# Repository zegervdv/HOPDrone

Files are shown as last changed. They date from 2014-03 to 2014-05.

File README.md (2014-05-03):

HOPDrone
========

Indoor localization for drones

## Code

For Least Mean Square implementation: checkout `code-lms`.

For Kalman implementation: checkout `code-kalman`.

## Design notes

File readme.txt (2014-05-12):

-- besluit !!
-- design vereisten
-- accelerometer => niet enkel handig voor kalman maar ook voor energiebesparing
	voelt de accelerometer een versnelling dan kan de filter worden aangezet (dynamic power management)
-- nlos => lange rise time(zorg voor redundantie en smijt nlos metingen eruit of sla een stap over na het opmerken van nLos en pas dead reckoning toe) 
   ook saturatie resultaten mag je niet zomaar gebruiken
-- kalman filter bank => meerdere parallelle filters ( 1 voor bv stilstaan, 1 voor snel voortbewegen, ...)
		--> residu: vergelijk de te verwachten waarde met wat je uitkomt, is dit sterk verschillend dan geef je aan die parallelle filter een laag gewicht

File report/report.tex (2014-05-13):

\documentclass[a4paper]{article}        % Standaard een kolom layout
\usepackage[english]{babel}             % Stel woordafbrekingen en referentienamen in
\usepackage{graphicx}                   % Afbeeldingen weergeven
\usepackage{float}                      % Figuren op plaats waar ze gedefinieerd staan: [H]
\usepackage{lmodern}                     % Lettertype instellen op Helvetica
\usepackage[T1]{fontenc}
\usepackage[hidelinks]{hyperref}        % Referenties aanklikbaar in PDF, geen kaders rond weergeven
\usepackage{siunitx}                    % SI unit symbolen
\usepackage{amsmath}                    % Matrices en vergelijkingen
\usepackage{subcaption}                 % Subfiguren
\usepackage[parfill]{parskip}			% Niet inspringen aan begin alinea
\usepackage{epstopdf}

% \title{Hardware Design Project\\ Designing a drone positioning sensor}
% \author{Laurens Bogaert\\Thomas Deckmyn\\Zeger Van de Vannet}
% \date{\today}

\begin{document}

\include{titel}
% Inhoudstafel
\newpage
  \tableofcontents
\newpage

\section{Introduction}

The goal for this project is to make it possible to accurately localize drones indoors. This is a necessity when we, for example, want the drone to fly autonomously. GPS can be used outdoors but even then GPS is not ideal because of its limited accuracy (approximately $\SI{3}{\meter}$ in the azimuth plane and even worse in terms of determining the height of the drone). \\\\
To perform the indoor localization we will use a custom setup comprising of the TIME DOMAIN\texttrademark PulsOn 410 UWB module\footnote{\url{http://www.timedomain.com/p400.php}}, that relies on pulses, which have an UWB spectrum, to obtain distance measurements between two modules. Several of these P410 (or RCM) modules are placed at known locations in the room and act as anchors to determine the current location of the drone based on triangulation.

 In this project we will develop a custom UWB antenna that will be mounted on the drone and will be streamlined in order to reduce possible drag. Also, an extra circuit board will be designed to connect a microcontroller to one of the RCM P410 modules in order to process the measurements and determine the position. These modules can be used both for ranging measurements, as well as for wireless communication. The module with the microcontroller is attached to the drone and several other RCM modules are placed in the room or building to serve as anchor points. The microcontroller will perform all calculations needed to determine its position based on different localization algorithms. An additional RCM is connected to a computer which acts as a central control unit and also allows to visualize the position of the drone in a GUI in real time. 

\section{Antenna Design}
	
	 The P410 modules are already equipped with a TIME DOMAIN\texttrademark Broadspec UWB Antenna, a dipole that is omnidirectional in the azimuth plane. We will use the specifications of this antenna as design parameters for our own UWB antenna. The critical design parameters are listed below. 

	\begin{itemize}
		\item Radiate in the $\SI{3.1}{\giga\hertz}$ - $\SI{5.3}{\giga\hertz}$ band
		\item Nominal gain $\approx \SI{3}{\decibel}$
		\item Linear phase characteristic
		\item Efficiency $\approx$ 90\%	

	\end{itemize}

	In an indoor environment reflective surfaces are omnipresent, e.g. walls, metal cabinets etc. Hence multipath can be a severe problem if not taken into account. The ranging done by the RCM modules is performed by measuring the round trip time of a pulse travelling to an anchor point (with a well known location) and back. When multipath occurs the module mounted on the drone will receive multiple signals from an anchor point, i.e. reflected and direct waves. The reflected waves will have an added time delay because of which the module will not be able to obtain the correct distance. 
	The P410 modules used for this project already account for multipath, thus it will be no issue for the development of the indoor localization system.  

	\subsection{Antenna Topology and Design}
	\label{subsec:ant_design}

	At first we experiment with a few conventional UWB topologies like a bow tie and a barbell shape (see Figure \ref{fig:topologies}). After optimisation and simulation in ADS, we conclude that the simulated S-parameters and gain are not compliant with the design parameters above. Obtaining a linear phase characteristic with these topologies proves to be very hard as well.  

		\begin{figure}[H]
		\begin{subfigure}{0.5\textwidth}
			\centering
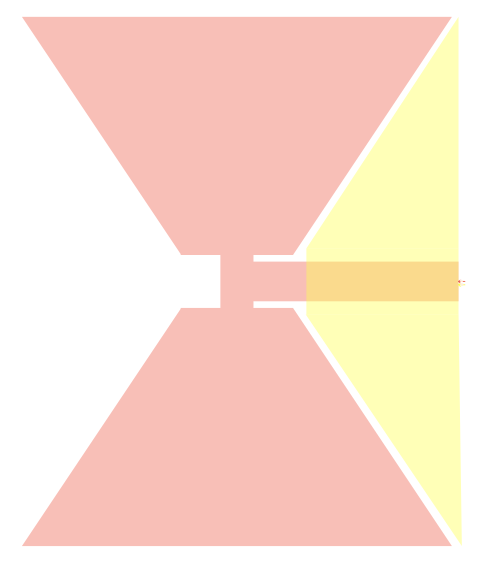
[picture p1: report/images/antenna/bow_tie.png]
			
			\caption{Bow Tie Topology}
		\end{subfigure}
		\begin{subfigure}{0.5\textwidth}
			\centering
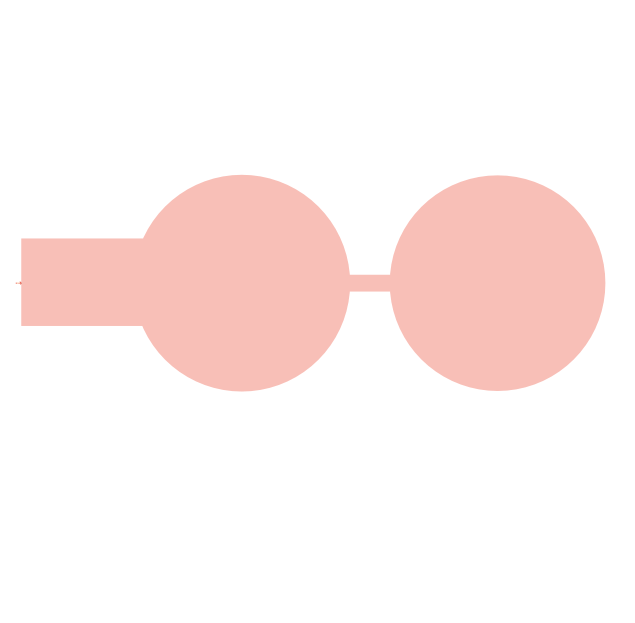
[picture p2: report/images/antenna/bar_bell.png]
			
			\caption{Barbell Topology}
		\end{subfigure}
		\caption{UWB Antenna Topologies}
		\label{fig:topologies}
		\end{figure} 

	The substrate material that is being used to design the antenna is \textit{Black Foam} with a low relative permittivity $\epsilon_r = 1.495$. Hence we encounter a practical problem with respect to the dimension of the antenna, i.e. if the antenna needs to be constructed with this substrate, its dimension will be too large to mount on the drone. Thus for the remaining part of the design process we opt for an \textit{Aromated Polyurethane} substrate with a higher $\epsilon_r = 2.55$, which allows us to work with smaller dimensions while radiating in the same frequency band. 

	After experimenting with the aforementioned exotic topologies, we redo the design starting from a rectangular microstrip patch antenna. The length of the patch determines the resonance frequency of the device, while the width has an influence on the radiated power. A wider patch means less resonance resistance, hence more bandwidth and a higher efficiency. 
	We want the resonance frequency of the patch to be in the predefined frequency band $\SI{3.1}{\giga\hertz}$ - $\SI{5.3}{\giga\hertz}$ and thus choose $f_0 = \SI{4.2}{\giga\hertz}$. Using Equation \eqref{eq:width_patch} we calculate the desired width of the patch.
	\begin{equation} 
	L = \frac{c}{2 f_r \sqrt{\epsilon_r}}
	\label{eq:width_patch}
	\end{equation}

  The bandwidth of the antenna needs to be very wide, thus, as explained above, we would be tempted to increase the width of the patch to obtain a larger bandwidth. Again, we are limited by the dimensions of the drone, because it needs to be fitted onto it and we do not want the antenna to interfere too much with the aerodynamics. To increase the bandwidth we apply another technique, i.e. adding stairs to the rectangular patch and optimizing their dimensions to obtain the desired bandwidth. Also, we introduce a partial ground plane (since UWB and a infinite ground plane do not coexist). We optimize the dimensions of the ground plane, to realize an approximately flat $S_{11}$ and a linear phase characteristic in the wanted frequency band. The final antenna lay-out is shown in Figure \ref{fig:patch_stairs} and the optimized dimensions are given in \autoref{tab:dimensions}.

	\begin{figure}[H]
	\centering
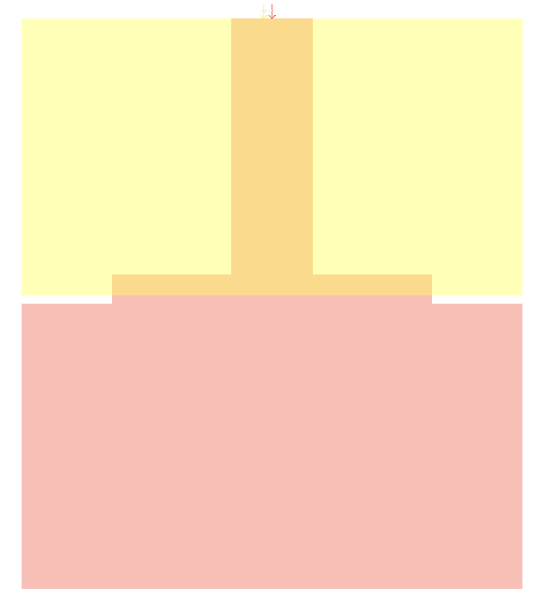
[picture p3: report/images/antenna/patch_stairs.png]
		
		\caption{Rectangular patch antenna with added stairs and partial ground plane}
		\label{fig:patch_stairs}
	\end{figure}

	\begin{table}[H]
	\centering
	\begin{tabular}{|c|c|}
		\hline
		\multicolumn{2}{|c|}{\textbf{Antenna}} \\ \hline
		L & $\SI{20.5}{\milli\meter}$ \\ \hline
		W & $\SI{36}{\milli\meter}$ \\ \hline
		$W_{stair}$ & $\SI{8.6}{\milli\meter}$ \\ \hline
		$H_{stair}$ & $\SI{2.1}{\milli\meter}$ \\ \hline
		\multicolumn{2}{|c|}{\textbf{Ground Plane}} \\ \hline
		L & $\SI{19.2}{\milli\meter}$ \\ \hline
		W & $\SI{36}{\milli\meter}$ \\ \hline 
	\end{tabular}
	\caption{Optimized dimensions for antenna and partial ground plane}
	\label{tab:dimensions}
	\end{table}

	\begin{figure}[H]
	\centering
	\begin{subfigure}[b]{0.52\textwidth}
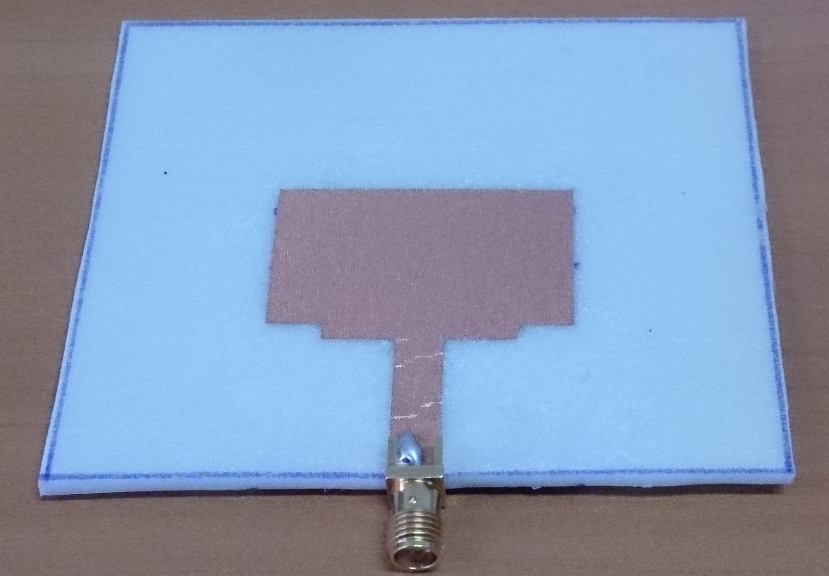
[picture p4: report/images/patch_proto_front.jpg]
                
                \caption{Front side prototype antenna}
                \label{fig:front_prototype}
        \end{subfigure}%
  ~      
        \begin{subfigure}[b]{0.5\textwidth}
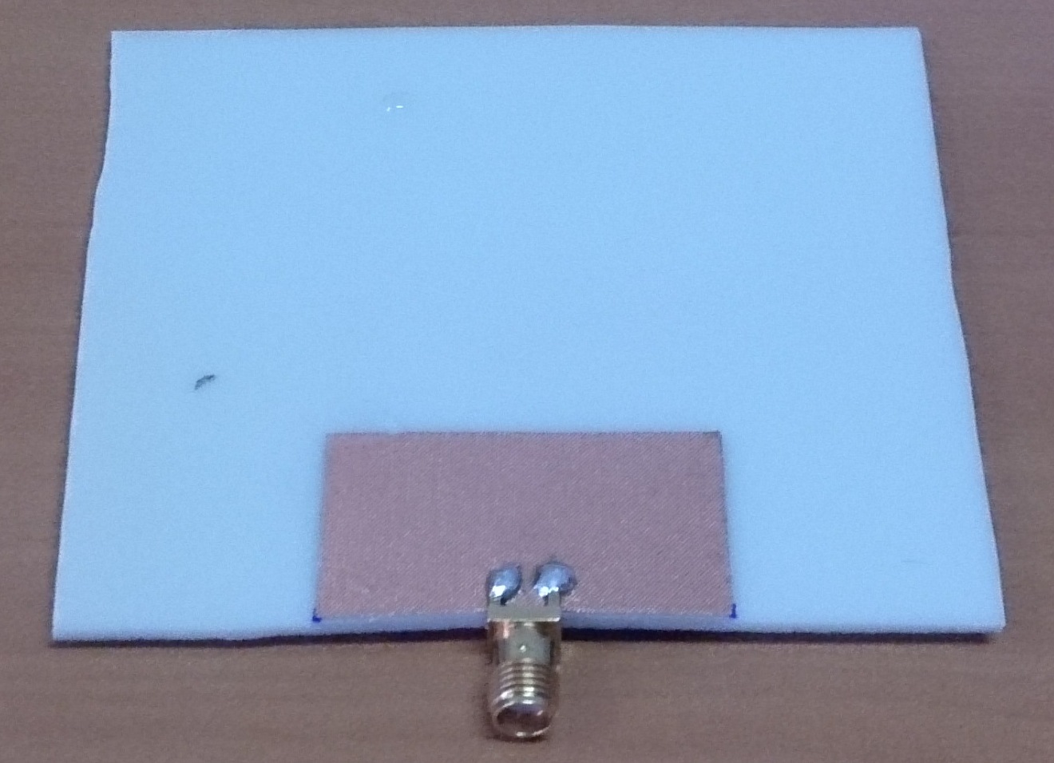
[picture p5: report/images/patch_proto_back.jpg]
                
                \caption{Back side prototype antenna}
                \label{fig:back_prototype}
        \end{subfigure}
	\end{figure}

	\subsection{Simulation}
		While designing the antenna, simulations in ADS Momentum\footnote{http://www.home.agilent.com/en/pc-1297113/advanced-design-system-ads} are used to confirm that the antenna's characteristics are as desired. In this section we will discuss the simulation results of the final design, as explained in the previous \autoref{subsec:ant_design}. 

		\begin{figure}[H]
		\begin{subfigure}{0.5\textwidth}
		\centering
			
			\caption{Simulated $S_{11}$}
		\end{subfigure}%
    ~
		\begin{subfigure}{0.5\textwidth}
		\centering
			
			\caption{Simulated phase response}
		\end{subfigure}
		\caption{Simulated characteristics for designed UWB antenna}
		\label{fig:S11_phase_design}
		\end{figure}

		\autoref{fig:S11_phase_design} shows that the $S_{11}$-parameter is below $\SI{-10}{\decibel}$, and relatively flat, in the desired frequency band. The phase characteristic proves to be approximately linear as well, which is in line with the design parameters. The gain is ca. $\SI{3}{\decibel}$ and the antenna efficiency is according to the simulation between 50\% and 96\%, with the latter occurring in the lower half of the frequency band. 
		Figure \ref{fig:ant_radpat_sim} shows the simulated radiation pattern of the designed UWB antenna.

		\begin{figure}[H]
		\centering
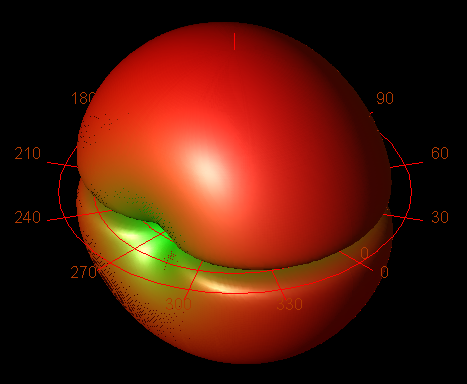
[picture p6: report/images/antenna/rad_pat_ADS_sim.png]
			
			\caption{Simulated radiation pattern at $\SI{4.5}{\giga\hertz}$}
			\label{fig:ant_radpat_sim}
		\end{figure}

	\subsection{Measurements}
		After the positive simulation results, we continue with the construction of the designed antenna. Due to a small misalignment between partial ground plane and antenna we need to construct a second version of the UWB antenna to obtain optimal results. Between these two versions, some minor adjustments are made to the design to further improve flatness of the $S_{11}$ and linearity of the phase, and to make it more robust to small alignment errors. The measured reflection coefficients of the two versions of the antenna are compared to the reference antenna and to the respective simulation in \autoref{fig:antenna_comp}. The initial measurements of the S-parameters of both versions suffered from noise due to common-mode current, which was solved by addition of a ferrite clamp.

		\begin{figure}[H]
			\centering
			
			\caption{Version 1 and 2 of constructed antenna compared to simulation and reference}
			\label{fig:antenna_comp}
		\end{figure}

		As seen in \autoref{fig:antenna_comp}, the first version of the antenna doesn't meet the pre-imposed design criteria, i.e.\ the $S_{11}$ is not less than $\SI{-10}{\decibel}$ over the entire frequency range of $\SI{3.1}{\giga\hertz}$ - $\SI{5.3}{\giga\hertz}$.
		The $S_{11}$ characteristic is improved by the better alignment in version 2 and the minor adjustments to the design.
		If we compare the measured $S_{11}$ to the simulation in Figure \ref{fig:S11_phase_design} we notice that the measured $S_{11}$ is below $\SI{-10}{\decibel}$ in the exact same frequency band that was predicted by the simulation. The main difference is the flatness of the characteristic and the resonance peak at approximately $\SI{5.2}{\giga\hertz}$. These deviations can be attributed to the manual fabrication of the antenna, the dimensions are not perfectly equal to the design and some slight misalignment is inevitable, or the fact that ADS Momentum assumes an infinite substrate to perform its simulations.\\\\

		\begin{figure}[H]
		\begin{subfigure}{0.5\textwidth}
			
			\caption{$\SI{3.1}{\giga\hertz}$}
		\end{subfigure}
		\begin{subfigure}{0.5\textwidth}
			
			\caption{$\SI{3.7}{\giga\hertz}$}
		\end{subfigure}
		\begin{subfigure}{0.5\textwidth}
			
			\caption{$\SI{4.8}{\giga\hertz}$}
		\end{subfigure}
		\begin{subfigure}{0.5\textwidth}
			
			\caption{$\SI{5}{\giga\hertz}$}
		\end{subfigure}
		\begin{subfigure}{\textwidth}
		\centering
			
			\caption{$\SI{5.3}{\giga\hertz}$}
		\end{subfigure}
		\caption{Radiation pattern in azimuth plane at different frequencies}
		\label{fig:ant_radpat}
		\end{figure}

		The radiation pattern in the azimuth plane of the designed UWB antenna at different frequencies is shown in Figure \ref{fig:ant_radpat}. We can state that the designed antenna is approximately omnidirectional in the azimuth plane up to $\SI{5}{\giga\hertz}$, which corresponds to the Broadspec UWB antenna used as a reference. It can also be seen that the radiation pattern starts to deviate from omnidirectional at $\SI{5}{\giga\hertz}$. Due to the resonance peak seen in Figure \ref{fig:antenna_comp} at approximately $\SI{5.2}{\giga\hertz}$ the antenna has a gain at $\SI{5.3}{\giga\hertz}$ that is larger than the pre-imposed $\SI{3}{\decibel}$. The transmit power of the RCM modules in standard mode can be adjusted within $[\SI{-31.6}{\decibel}m , \SI{-12.46}{\decibel}m]$ if needed, to comply with FCC regulations.\\\\
		
		\begin{figure}[H]
			\begin{subfigure}{0.5\textwidth}
			\centering
				
				\caption{$\SI{3.4}{\giga\hertz}$}
			\end{subfigure}
			\begin{subfigure}{0.5\textwidth}
			\centering
				
				\caption{$\SI{4.5}{\giga\hertz}$}
			\end{subfigure}
			\begin{subfigure}{\textwidth}
			\centering
				
				\caption{$\SI{5}{\giga\hertz}$}
			\end{subfigure}
		\caption{Cross section of radiation pattern in elevation plane}
		\label{fig:ant_radpat_elev}
		\end{figure}
			Figure \ref{fig:ant_radpat_elev} shows a cross section of the radiation pattern in the elevation plane at different frequencies. There is a zero in the radiation pattern for $\theta=0$ and $\theta=\pi$. The antenna will be mounted on the drone "upside down", i.e. $\theta$ = 0 will be oriented along the negative z-axis. As the drone will only pass directly over an anchor in very rare cases, the zero at $\theta=0$ will not cause problems for the localization system. Figure \ref{fig:mount_antenna} shows how the antenna will be mounted on the drone, thus the zero at $\theta=\pi$ is even beneficial as it minimizes the chance of interference and EMC problems inside the circuit of the drone. 

		\begin{figure}[H]
			\centering
			
			\caption{Mounting antenna on bottom of drone}
			\label{fig:mount_antenna}
		\end{figure}

\section{Location Algorithm}
	A first algorithm that can be used to determine the position of the drone is the \textit{Least Mean Square} algorithm. We will elaborate on this first and then compare the performance to the Unscented Kalman Filter, which will be used in the final system. 

	\subsection{Least Mean Square}
	\label{subsec:LMS}

		The LMS algorithm uses the distances between the drone and a number of well-known anchor points to determine the position. The UWB antenna mounted on the drone broadcasts a very short pulse to the anchors, which will return the same pulse when it is received. The board on the drone measures the time between sending the pulse and receiving the response. As the propagation speed in air of the pulse and the time it takes to process it at the anchors are known, the distance to the anchor points can be determined as follows:

		\begin{equation}
		\centering
			t_{roundtrip} = 2t_{propagation} + t_{process}
		\end{equation} 

		Because the time to process the pulse at the anchor is known, we are able to calculate the time it takes to bridge the distance from the drone to the anchor point or vice versa. With $c$ the speed of light ($\SI{3e8}{\meter\per\second}$) this results in an expression for the distance to anchor point $i$:

		\begin{equation}
		\centering
			d_i = c*t_{propagation}
		\end{equation}

		With $\vec{\textbf{x}}$ denoting the position vector $\begin{bmatrix} x & y & z \end{bmatrix}$ of the drone and $\vec{\textbf{x}_i}$ the position vector $\begin{bmatrix} x_i & y_i & z_i \end{bmatrix}$ of the $i^{th}$ anchor point, this distance can also be expressed as follows:

		\begin{align*}
		\centering
			d_i^2 &= (\vec{\textbf{x}} - \vec{\textbf{x}_i})(\vec{\textbf{x}} - \vec{\textbf{x}_i})^T \\
			&= x^2 - 2x_ix + x_i^2 + y^2 - 2y_iy + y_i^2 + z^2 - 2z_iz + z_i^2
		\end{align*}

		This equation is not linear in x, y and z and therefore it is hard to extract the position vector. With $d_N$ the distance to the $N^{th}$ anchor, the equation can be linearised as follows:

		\begin{align*}
		\centering
			d_i^2 - d_N^2 &= x^2 - 2x_ix + x_i^2 + y^2 - 2y_iy + y_i^2 + z^2 - 2z_iz + z_i^2 - d_N^2 \\
				&= 2x(x_N - x_i) + 2y(y_N - y_i) + 2z(z_N- z_i)+ (x_i^2 - x_N^2) + (y_i^2 - y_N^2)  + (z_i^2 - z_N^2) 
		\end{align*}

		This yields a matrix representation of the form $\textbf{A}\vec{\textbf{x}} = \textbf{B}$ which can be solved for the position vector $\vec{\textbf{x}}$.

	% subsection LMS (end)
	\subsection{Kalman Filtering}
	The second algorithm that is implemented is the Kalman Filter. This algorithm makes use of ``sensor'' fusion which in principle means that we try to combine data from several sensors to track the drone more accurately.
	Examples of sensors that we can use to improve the result are an accelerometer, a gyroscope, an altitude meter, etc.\\
	The iterative process of a Kalman filter consists of 2 distinct steps. First of all we will try to predict the next location by using results of the past (i.e. Kalman filtering is a method with a memory). 
	The second step of Kalman filtering consists of using the real measured data (distances and possibly also extra data) to update the memory of the filter by changing the matrices in the Kalman filter system.\\
	However, the matrix computations used in the implementation of the Kalman filter are based on Gaussian distributions. Hence, in real life (when we don't have Gaussian distributed data) we won't get as good performances as we get when simulating the Kalman filter.
	%CONCEPTUAL SOLUTION FOR THIS PROBLEM?
	
\subsection{Comparison between LMS and Kalman}

To compare both algorithms we generate a Gaussian movement and calculate the distance to each of the anchors in a noiseless channel. We generate the input distances for the algorithm by adding Gaussian noise to the ideal distances.
When we display the generated movement on a plot which also consists of the output locations of the Kalman filter and LMS algorithm we get \autoref{fig:paths}.
We notice on this Figure that the path is followed quite accurately, but to make a real comparison between the 2 algorithms we will have to zoom in on a part of the followed route. This is what is done in \autoref{fig:paths_zoom}.	\\\\
On \autoref{fig:paths_zoom} it can be seen that LMS is somewhat worse than the Kalman Filter. Note that the Kalman path is way smoother than the path followed according to LMS. This is because the Kalman uses memory and states that sudden discontinuities in the followed direction are very unlikely and thus the Kalman will follow a path that resembles a straight line locally. Hence, Kalman will only be useful if we use our algorithm to try to track a drone which doesn't change its course too abruptly.

			\begin{figure}[H]
				\centering
				
				\caption{Travelled paths according to the different algorithms}
				\label{fig:paths}
			\end{figure}

			\begin{figure}[H]
				\centering
				
				\caption{Travelled paths according to the different algorithms (zoom)}
				\label{fig:paths_zoom}
			\end{figure}

Now, we want to quantize the error made by adopting both algorithms. We choose as a distortion measure the mean squared error per dimension and let Matlab plot the cumulative distribution function of this mean squared error (\autoref{fig:cdf}). This cdf shows that the LMS indeed yields worse performances than the Kalman when a Gaussian-based path is followed and we don't introduce too much measure noise.
			
			\begin{figure}[H]
				\centering
				
				\caption{Cumulative distribution function for the different algorithms}
				\label{fig:cdf}
			\end{figure}

The mean squared error per dimension that was mentioned before is computed as follows:

\begin{equation}
MSE = \dfrac{1}{3}((x_{real}-x_{est})^2+(y_{real}-y_{est})^2+(z_{real}-z_{est})^2)
\end{equation}

On \autoref{fig:cdf}, a purple line is included which gives us the 90th percentile of the MSE:

\begin{table}[H]
\begin{center}
\begin{tabular}{ | r | l | }
    \hline
     & MSE [$m^2$] \\ \hline
    LMS & $\SI{1.95}{\square\meter}$ \\ \hline
    Kalman & $\SI{0.43}{\square\meter}$ \\
    \hline
\end{tabular}
\end{center}
\caption{Mean Squared Error: a comparison}
\label{table:MSE}
\end{table}

\section{PCB Design}

  As microcontroller we choose one from the STM32F4XX-series. These are powerful 32 bit ARM processors, which are sufficiently fast to process the data.
  To attach it to the ranging module, we design a PCB to hold the processor and its required decoupling. Communication with the module is provided by a USART interface.
  A voltage regulator yields a stable $\SI{3.3}{\volt}$ from different sources: either from an external battery or from the drone itself. Switching between both supplies can be done by moving a jumper.

  To improve the results from the Kalman filter, an accelerometer is also added to the design, which provides acceleration data in three dimensions. Communication with the accelerometer is done over the I2C interface.

  To protect the microcontroller from ESD damage, we add Zener diodes to every I/O pin, which will safely dispose of the harmful power injected into the system.
  We also use a full reference plane instead of strips to provide a low impedance path for return currents and to avoid big current loops, which may act as magnetic dipoles and thus radiate causing interference and crosstalk.  
  
  \begin{figure}[H]
    \begin{center}
      
      \caption{Assembled PCB without pin headers and connectors}
      \label{fig:final_pcb}
    \end{center}
  \end{figure}
  
\end{document}

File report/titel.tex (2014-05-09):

%  Titelblad

% Opmerking: gaat uit van een \baselinestretch waarde van 1.5 (die moet
% ingesteld worden voor het begin van de document environment)

\begin{titlepage}
%
% \setlength{\hoffset}{-1in}
% \setlength{\voffset}{-1in}
% \setlength{\topmargin}{1.5cm}
% \setlength{\headheight}{0.5cm}
% \setlength{\headsep}{1cm}
% \setlength{\oddsidemargin}{3cm}
% \setlength{\evensidemargin}{3cm}
% \setlength{\footskip}{1.5cm}
% \enlargethispage{1cm}
% \textwidth en \textheight hier aanpassen blijkt niet te werken

\fontsize{12pt}{14pt}
\selectfont

\begin{center}



\vspace{0.5cm}

Faculty of Engineering

\vspace{3.5cm}

\fontseries{bx}
\fontsize{17.28pt}{21pt}
\selectfont

Hardware Design Project\\
Design of a Drone Positioning Sensor

\fontseries{m}
\fontsize{12pt}{14pt}
\selectfont

\vspace{.6cm}

by 

\vspace{.4cm}

Laurens \textsc{Bogaert}\\
Thomas \textsc{Deckmyn}\\
Zeger \textsc{Van de Vannet}

\vspace{3.5cm}

Promotors: Prof.~Dr.~Ir.~H.~\textsc{Rogier},
			Prof.~Dr.~Ir.~H.~\textsc{Steendam}\\
Assistant: Ir.~S.~\textsc{Van de Velde}\\

\vspace{2cm}

\vspace{1cm}

Academic Year 2013--2014

\end{center}
\end{titlepage}

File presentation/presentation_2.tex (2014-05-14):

\documentclass{beamer}
\usetheme[faculty=tw,language=dutch,framenumber,totalframenumber]{UniversiteitGent}
\usepackage{siunitx}
\usepackage{multicol}
\usepackage[]{hyperref}
\usepackage{soul}
\usepackage{tikz}
\usepackage{epstopdf}
\usepackage{tikz}
\usepackage{circuitikz}

\newcommand{\hcancel}[1]{%
    \tikz[baseline=(tocancel.base)]{
        \node[inner sep=0pt,outer sep=0pt] (tocancel) {#1};
        \draw[red] (tocancel.south west) -- (tocancel.north east);
        \draw[red]  (tocancel.north west) -- (tocancel.south east);
    }%
}%

% \addtobeamertemplate{navigation symbols}{}{%
%     \usebeamerfont{footline}%
%     \usebeamercolor[fg]{footline}%
%     \hspace{1em}%
%     \insertframenumber/\inserttotalframenumber
% }

\title{\textbf{Hardware Ontwerpproject}}
\subtitle{Design of a Drone Positioning Sensor}
\author{Laurens Bogaert, Thomas Deckmyn \& Zeger Van de Vannet\\Groep 5}

\AtBeginSection[]{
  \begin{frame}
    \begin{multicols}{2}
    \frametitle{Inhoudstafel}
    \tableofcontents[currentsection]
  \end{multicols}
  \end{frame}
}

\usepackage{pifont}

\begin{document}

\begin{frame}
  \titlepage
\end{frame}

\section{Inleiding}
\subsection{Situering}
  \begin{frame}
    \frametitle{Situering}
    GPS:
    \begin{itemize}
        \item Niet voor binnen
        \item Onnauwkeurig (3 m)
        \item Hoogtemeting beperkt
    \end{itemize}
    Toepassing:
     \begin{itemize}
        \item Autonoom vliegen
    \end{itemize}   
  \end{frame}
  \begin{frame}
  \frametitle{Oplossing}
   \begin{columns}
    \begin{column}{0.5\textwidth}
  	\begin{itemize}
  		\item Afstandsbepaling
  		\item Communicatie
  	\end{itemize} 
    \end{column}
    \begin{column}{0.5\textwidth}
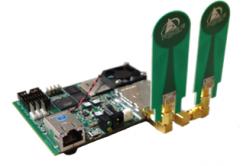
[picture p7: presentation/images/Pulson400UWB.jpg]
  	
    \end{column}
    \end{columns}
  \end{frame} 
  \begin{frame}
    \frametitle{Situering}
    3 onderdelen:
    \begin{itemize}
      \item PCB + Controller
      \item Algoritmes
      \item Antenne
    \end{itemize}
  \end{frame}
\subsection{Planning}
  \begin{frame}
    \frametitle{Planning}
    \begin{tabular}{|l | l | l|}
      \hline
      Week & Titel & Status\\
      \hline
      1 & Toekenning onderwerp & \checkmark\\
      2 & Literatuurstudie \& $1^{ste}$ algoritme & \checkmark\\
      3 & Kennismaking ADS \& $2^{de}$ algoritme & \checkmark\\
      4 - 6 & Antenne design (L \& T) \& PCB-ontwerp (Z) & \checkmark \\
      7 & Afwerking $2^{de}$ algoritme \& Fabricage Antenne (T) & \checkmark \\
       & Vergelijking Algoritmes & \checkmark\\
      8 & Uitmeten Antenne  & \checkmark \\
      \hline
    \end{tabular}
  \end{frame}
  
    \begin{frame}
    \frametitle{Planning}
    \begin{tabular}{|l | l | l|}
      \hline
      Week & Titel & Status\\
      \hline
      Paas 1 \& 2 & Implementatie microcontroller & \checkmark\\
      9 & Bestukking PCB  & \checkmark\\
      10 & Afwerken Implementaties  & \checkmark\\
      11 & Afwerken (debuggen) + verslag schrijven & \checkmark \\
      12 & Afwerken (debuggen + synthese) + presentatie & \checkmark \\
      \hline
    \end{tabular}
  \end{frame}

\section{PCB Design}
\subsection{Onderdelen}
  \begin{frame}
    \frametitle{Vereisten}
    \begin{itemize}
      \item Microcontroller: verwerking van metingen tot positie
      \item Accelerometer:
      \begin{itemize}
      	\item Preciezere positiebepaling
      	\item Dynamic Power Management
      \end{itemize}
      \item Klein \& licht
    \end{itemize}
  \end{frame}
  \begin{frame}
  	\frametitle{EMC}
      \begin{columns}[t]
        \begin{column}[T]{.5\textwidth}
          \begin{itemize}
            \item Volledig grondvlak
            \item ESD bescherming: Zener diodes
          \end{itemize}
        \end{column}
        \begin{column}[T]{.5\textwidth}
          \centering
          \begin{tikzpicture}
            \node [ground] {};
            \draw (0,0) to[sD*] (0,2);
            \draw (-2,2) -- (2,2);
          \end{tikzpicture}
        \end{column}
      \end{columns}
  \end{frame}
  \begin{frame}
    \begin{figure}
      \begin{center}
        
      \end{center}
    \end{figure}
  \end{frame}
\section{Algoritmes}
\subsection{Ankers}
  \begin{frame}
    \frametitle{Opstelling}
    \begin{figure}
      \begin{center}
        
      \end{center}
    \end{figure}
  \end{frame}
  
  \begin{frame}
    \frametitle{Ankers}
    \begin{itemize}
      \item Gekende positie
      \item Afstand via pulsen $\Rightarrow$ UWB
      \item Meetruis
    \end{itemize}
    \begin{figure}
      \begin{center}
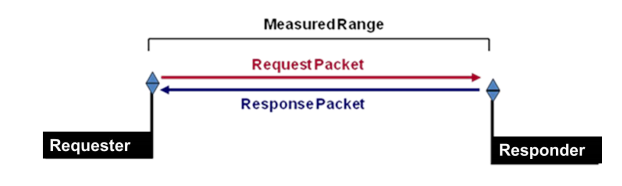
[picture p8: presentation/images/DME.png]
        
      \end{center}
    \end{figure}
  \end{frame}
\subsection{Lokalisatie Algoritme}
  \begin{frame}
    \frametitle{Algoritmes}
    \begin{itemize}
      \item Least Squares
      \item Kalman 
    \end{itemize}
  \end{frame}
  \begin{frame}
    \frametitle{Least Squares}
    \begin{itemize}
      \item Geen geheugen
        \begin{itemize}
          \item Geen invloed van het verleden
        \end{itemize}
    \end{itemize}
      \begin{figure}
      \centering
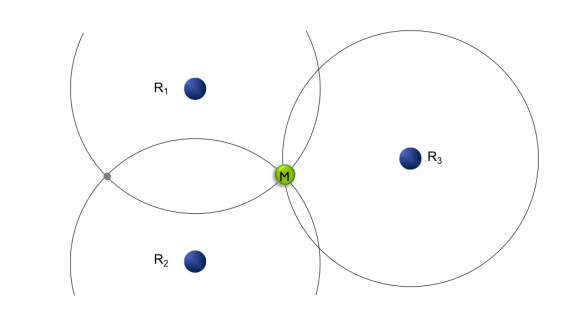
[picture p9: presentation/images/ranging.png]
        
    \end{figure}
  \end{frame}
  \begin{frame}
  \frametitle{Wat bij overdimensionering?}

    \begin{itemize}
    \item Laat NLOS metingen vallen
    \item Minimaliseer de gemiddelde kwadratische fout
    \end{itemize}
          \begin{figure}
      \centering
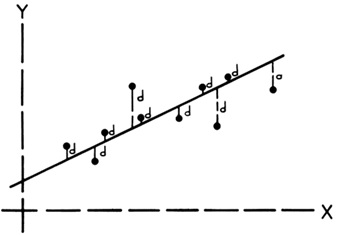
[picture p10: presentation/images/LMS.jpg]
        
    \end{figure}
  \end{frame}
  \begin{frame}
    \frametitle{Kalman Filter}
    \begin{itemize}
      \item Geheugen $\Rightarrow$ matrices
      \item Bewegingsvrijheid van de drone is beperkt
      \item 2 onderdelen:
        \begin{itemize}
          \item Voorspellen
          \item Meten en updaten
        \end{itemize}
    \end{itemize}
  \end{frame}
  \begin{frame}
    \frametitle{Uitbreiden Kalman Filter}
    \begin{itemize}
      \item Extra Sensoren (Sensor Fusion)
        \begin{itemize}
          \item Accelerometer
          \item Gyroscoop
          \item Hoogtemeter
          \item \ldots
        \end{itemize}
      \item Doel: nauwkeuriger volgen
    \end{itemize}
  \end{frame}
\subsection{Resultaten}
  \begin{frame}
    \frametitle{Resultaten: Simulaties}
    \begin{columns}[c]
      \begin{column}{.5\textwidth}
        \begin{figure}
          \begin{center}
            
          \end{center}
        \end{figure}
      \end{column}
      \begin{column}{.5\textwidth}
        \begin{figure}
          \begin{center}
            
          \end{center}
        \end{figure}
      \end{column}
    \end{columns}
  \end{frame}
  
  \begin{frame}
    \frametitle{Resultaten: Simulaties}
    \begin{columns}[c]
  \begin{column}{0.5\textwidth}
    \begin{itemize}
      \item Gemiddelde kwadratische fout
      \end{itemize}
      \begin{equation*}
      \begin{split}
MSE = \dfrac{1}{3}((x_{real}-x_{est})^2+\\(y_{real}-y_{est})^2+\\(z_{real}-z_{est})^2 )
\end{split}
\end{equation*}
\begin{itemize}
      \item 90-ste percentiel
    \end{itemize}
    \end{column}

    \begin{column}{0.5\textwidth}
    \begin{figure}
      \begin{center}
        
      \end{center}
    \end{figure}
    \end{column}
    \end{columns}

  \end{frame}
  
  \begin{frame}
    \frametitle{Least Squares vs. Kalman Filter}
    \begin{center}
    \begin{tabular}{|l|l|}
      \hline
      Least Squares & Kalman Filter \\
      \hline
      (+) Eenvoudiger & (-) Complexer \\
      (-) Ruwere schatting & (+) Nauwkeuriger \\
      \hline
    \end{tabular}
    \end{center}
  \end{frame}

  \addtocontents{toc}{\newpage}

\section{Microcontroller}
\subsection{Algemeen}
\begin{frame}
\begin{itemize}
\frametitle{Algemeen}
\item Matlab naar microcontroller
\item Refresh rate: $\pm$ 3 Hz
\begin{itemize}
\item Te laag voor autonoom vliegen
\end{itemize}
\end{itemize}
\end{frame}
\begin{frame}
\frametitle{LOS vs. NLOS: Rise Time}
 \begin{figure}
      \begin{center}
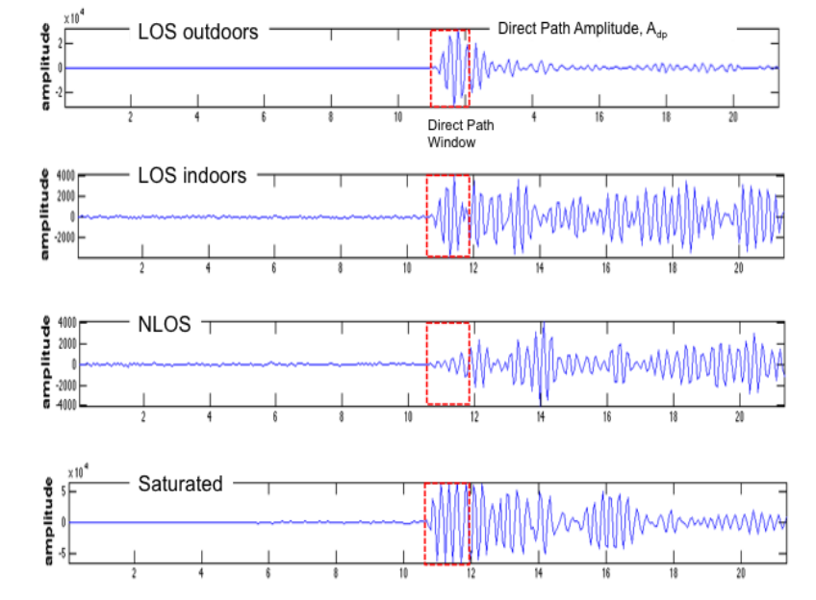
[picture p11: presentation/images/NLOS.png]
        
      \end{center}
    \end{figure}
\end{frame}

\subsection{Problemen}
\begin{frame}
\frametitle{Problemen: 3D nauwkeurigheid}
\begin{itemize}
\item Matlab: goede spreiding in de 3D ruimte
\item Praktijk: kleinere z-spreiding ankers
\begin{itemize}
\item Lagere nauwkeurigheid in de z-richting
\end{itemize}
\end{itemize}
\end{frame}
\begin{frame}
\frametitle{Problemen: Gaussiaanse beweging}
\begin{itemize}
\item Kalman is gebaseerd op Gaussiaanse bewegings- en ruismodellen
\begin{itemize}
\item Te scherpe bochten 
\end{itemize}
\end{itemize}
\end{frame}
\subsection{Uitbreidingen}
\begin{frame}
\frametitle{Eventuele uitbreiding}
Kalman tunen via parameters:
\begin{itemize}
\item bewegingsvariantie
\item ruisvariantie
\item ...
\end{itemize}

Voorstel:
Model afhankelijk van type beweging\\
\begin{itemize}
\item parallelle filterbank
\end{itemize}
\end{frame}

\begin{frame}
\frametitle{Kalman Filterbank}
Parallelle filterbank:
\begin{itemize}

\item Stilstaan
\item Traag bewegen
\item Snel bewegen
\end{itemize}

Geef verschillende gewichten

\end{frame}

\section{UWB Antenne}
\subsection{Referentie}
  \begin{frame}
  \frametitle{Referentie}
  \begin{columns}[c]
  \begin{column}{0.5\textwidth}
    \begin{itemize}
      \item BroadSpec\texttrademark  UWB Antenne 
      \item Dipool: omni in azimuth
      \item Ontwerpsparameters:
      \begin{itemize}
        \item $\SI{3.1}{\giga\hertz}$ - $\SI{5.3}{\giga\hertz}$
        \item Gain nominaal $\approx \SI{3}{\decibel}$ 
        \item Lineaire fase respons
        \item Effici\"entie $\approx$ 90\%
      \end{itemize}
    \end{itemize}
    \end{column}

    \begin{column}{0.5\textwidth}
    \centering
      
    \end{column}
    \end{columns}
  \end{frame}

  \begin{frame}
  \frametitle{Ontwerp UWB Antenne}
  \begin{itemize}
    \item Start: Rechthoekige Patch Antenne
      \begin{itemize}
        \item Lengte: Resonantie frequentie $f_0 = \SI{4.2}{\giga\hertz}$
              \begin{align}  L = \frac{c}{2 f_r \sqrt{\epsilon_r}}  \nonumber \end{align}
        \item Breedte: \begin{align} \text{Uitgestraald vermogen} \nonumber & \implies \text{Resonantie weerstand} \downarrow \\ & \implies \text{Bandbreedte} \uparrow, \text{Effici\"entie} \uparrow \nonumber \end{align}

      \end{itemize}
    \item Dimensies drone! $\implies$ Andere manier BW $\uparrow$ 
    \end{itemize}
  \end{frame}

  \begin{frame}
  \frametitle{Ontwerp UWB Antenne}
  
  \begin{columns}[c]
  \begin{column}{0.5\textwidth}
    \begin{itemize}
      \item Toevoegen \textit{Trap} $\implies$ BW $\uparrow$
      \item Partieel grondvlak
      \begin{itemize}
        \item Optimaliseren dimensies \begin{align} & \implies \text{Vlakke } S_{11} \nonumber \\ & \implies \text{Lineaire fase} \nonumber \end{align}
      \end{itemize}

    \end{itemize}
  \end{column}

  \begin{column}{0.5\textwidth}
  \centering
    
  \end{column}
  \end{columns}
  \end{frame}

\subsection{Simulatie}
  \begin{frame}
  \frametitle{ADS Simulatie}
    \begin{columns}[c]
      \begin{column}{0.5\textwidth}
      \begin{itemize}
        \item $S_{11} < \SI{-10}{\decibel}$: \\ $\SI{3.1}{\giga\hertz}$ - $\SI{6.7}{\giga\hertz}$
      \end{itemize}
        \begin{figure}
          
        \end{figure}

      \end{column}

      \begin{column}{0.5\textwidth}
      \begin{itemize}
        \item Lineaire fase respons: \\ OK
      \end{itemize}
        \begin{figure}
          
        \end{figure}
      \end{column}
    \end{columns}
  \end{frame}

  \begin{frame}
  \frametitle{ADS Simulatie}
    \begin{columns}[c]
      \begin{column}{0.5\textwidth}
      \begin{itemize}
        \item Effici\"entie 50\% - 96\% in gewenste band
      \end{itemize}
        \begin{figure}
          
        \end{figure}

      \end{column}

      \begin{column}{0.5\textwidth}
      \begin{itemize}
        \item Gain $\approx \SI{3}{\decibel}$ in gewenste band 
      \end{itemize}
        \begin{figure}
          
        \end{figure}
      \end{column}
    \end{columns}
  \end{frame}

\subsection{Prototype}
  \begin{frame}
  \frametitle{Prototype}
    \begin{itemize}
      \item Manuele fabricatie 
      \begin{itemize}
      	\item Foute alignatie t.o.v. grondvlak
      	\item Prototype versie 2.0
      \end{itemize} 
    \end{itemize}
    \begin{columns}[c]
    \begin{column}{0.5\textwidth}
      
    \end{column}%
    \begin{column}{0.5\textwidth}
      
    \end{column}
    \end{columns}
  \end{frame}

\subsection{Metingen}
  \begin{frame}
  \frametitle{Metingen}

	  \begin{columns}[c]
	  \begin{column}{0.5\textwidth}
	  	\begin{itemize}
	  		\item Vergelijking met referentie
	  		\begin{itemize}
	  			\item Versie 1: $S_{11} > \SI{-10}{\decibel}$ 
	  		\end{itemize}
	  		\item Resonantie piek @ $\SI{5.2}{\giga\hertz}$  
	  		\begin{itemize}
	  			\item $\neq$ Simulatie
	  			\item Manuele fabricatie
	  			\item ADS: oneindig substraat
	  		\end{itemize}
	  	\end{itemize}
	  \end{column}%
	  \begin{column}{0.5\textwidth}
	  	
	  \end{column}
	  \end{columns}
  \end{frame}

  \begin{frame}
  \frametitle{Metingen}
  	\begin{columns}[c]
  	\begin{column}{0.5\textwidth}
  		\begin{itemize}
  			\item Stralingspatroon azimuth
  			\begin{itemize}
  				\item $\approx$ Omnidirectioneel tot $\SI{5}{\giga\hertz}$
  				\item Conform ontwerpsparameters\\
  			\end{itemize}
  			\item Resonantie @ $\SI{5.2}{\giga\hertz}$
  			\begin{itemize}
  				\item Niet omni
  				\item Gain $\uparrow$
  			\end{itemize}
  			\item Zendvermogen RCM instelbaar
  			\begin{itemize}
  				\item $[\SI{-31.6}{\decibel}m , \SI{-12.46}{\decibel}m]$
  			\end{itemize}
  		\end{itemize}
  	\end{column}
  	\begin{column}{0.5\textwidth}
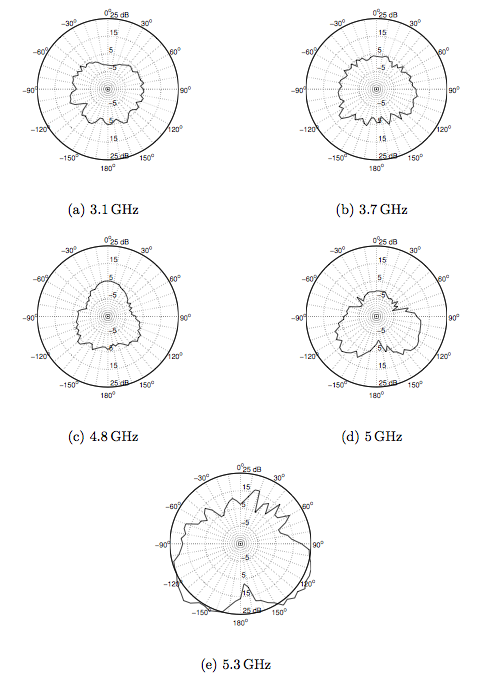
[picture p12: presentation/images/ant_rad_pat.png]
  		
  	\end{column}
  	\end{columns}
  \end{frame}

  \begin{frame}
  \frametitle{Metingen}
    \begin{columns}[c]
    \begin{column}{0.5\textwidth}
      \begin{itemize}
        \item Stralingspatroon elevatie
        \begin{itemize}
          \item Twee nullen: \\ $\theta=0$ en $\theta=\pi$
          \item Drone recht boven anker: zeldzaam $\implies$ \hcancel{$\theta = 0$}
        \end{itemize}
      \end{itemize}
    \end{column}
    \begin{column}{0.5\textwidth}
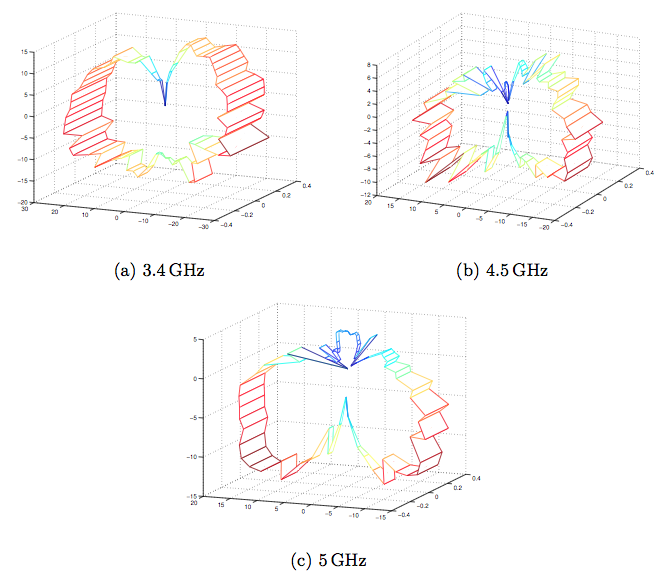
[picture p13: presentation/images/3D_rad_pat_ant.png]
      
    \end{column}
    \end{columns}
  \end{frame}

  \begin{frame}
  \frametitle{Metingen}
    \begin{columns}
    \begin{column}{0.5\textwidth}
      \begin{itemize}
        \item Plaatsing: Drone in nul 
        \begin{itemize}
          \item \hcancel{$\theta=\pi$}
          \item Risico EMC-problemen $\downarrow$
        \end{itemize}
      \end{itemize}
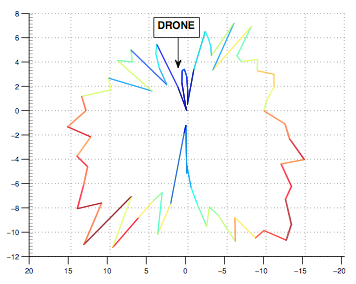
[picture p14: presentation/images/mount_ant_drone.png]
      
    \end{column}
    \begin{column}{0.5\textwidth}
      \begin{itemize}
        \item Antenne effici\"entie
        \begin{itemize}
          \item Simulatie: $\frac{1}{exp(f)}$
          \item Tussen 10\% en 50\%
        \end{itemize}
      \end{itemize}
      
    \end{column}
    \end{columns}
  \end{frame}

\subsection{Conclusie}
  \begin{frame}
  \frametitle{Conclusie Ontwerp Antenne}
    \begin{itemize}
      \item Antenne functioneert correct in systeem
      \item Openstaande problemen:
      \begin{itemize}
        \item Resonantie piek @ $\SI{5.2}{\giga\hertz}$ \\ $\implies$ Verbeter omnidirectionaliteit
        \item Antenne effici\"entie
        \item Aerodynamica
      \end{itemize}
    \end{itemize}

  \end{frame}

\section{Besluit}
  \begin{frame}
  \frametitle{Besluit}
    \begin{itemize}
      \item Antenne functioneert correct voor plaatsbepaling
      \item Algoritmes succesvol ge\"implementeerd op microcontroller
        \begin{itemize}
          \item Least Squares 3D
          \item Unscented Kalman Filter
        \end{itemize}
      \item PCB functioneert correct
      \item GUI aangepast
        \begin{itemize}
          \item Switchen tussen algoritmes
          \item Positie drone visueel voorstellen in 3D
          \item Accelerometer data plotten
        \end{itemize} 
      \item Volledig systeem kan gedemonstreerd worden
    \end{itemize}

  \end{frame}

\section{Demonstratie}
\begin{frame}[c]
  \begin{center}
    \Huge Demonstratie
  \end{center}
\end{frame}

\begin{frame}[label=FINAL_TOC]
  \begin{multicols}{2}
    \frametitle{Inhoudstafel}
    \tableofcontents[]
  \end{multicols}
\end{frame}
\end{document}

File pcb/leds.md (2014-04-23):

| ref | size | lum. int | colour | voltage  | current | resistor |
| --- | ---- | --- | --- | --- | --- | --- |
| 2099239 | 0805 | 12 | green  | 2.2V | 20mA | 56 |
| 2099236 | 0805 | 15 | red | 2V | 20mA | 68 |

#Pin mapping

| pin  | name | colour | function |
| ---  | --- | --- | --- |
| PD12 | LED1 | red | error |
| PE14 | LED2 | green  | |
| PD14 | LED3 | green  | |
| n/a  | PWR | red | Power |

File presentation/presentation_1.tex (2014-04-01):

\documentclass{beamer}
\usetheme[faculty=tw,language=dutch,framenumber,totalframenumber]{UniversiteitGent}
\usepackage{siunitx}
\usepackage{multicol}

\title{\textbf{Hardware Ontwerpproject}}
\subtitle{Indoor lokalisatie voor drones}
\author{Laurens Bogaert, Thomas Deckmyn \& Zeger Van de Vannet\\Groep 5}

\AtBeginSection[]
{
  \begin{frame}
    \begin{multicols}{2}
    \frametitle{Inhoudstafel}
    \tableofcontents[currentsection]
  \end{multicols}
  \end{frame}
}

\usepackage{pifont}

\begin{document}

\begin{frame}
  \titlepage
\end{frame}

\section{Inleiding}
\subsection{Situering}
  \begin{frame}
    \frametitle{Situering}
    GPS:
    \begin{itemize}
        \item Niet voor binnen
        \item Onnauwkeurig (3 m)
        \item Hoogtemeting beperkt
    \end{itemize}
  \end{frame}
  \begin{frame}
    \frametitle{Situering}
    3 onderdelen:
    \begin{itemize}
      \item Algoritmes
      \item Antenne
      \item PCB + Controller
    \end{itemize}
  \end{frame}
\subsection{Planning}
  \begin{frame}
    \frametitle{Planning}
    \begin{tabular}{|l | l | l|}
      \hline
      Week & Titel & Status\\
      \hline
      1 & Toekenning onderwerp & \checkmark\\
      2 & Literatuurstudie \& $1^{ste}$ algoritme & \checkmark\\
      3 & Kennismaking ADS \& $2^{de}$ algoritme & \checkmark\\
      4 - 6 & Antenne design (L \& T) \& PCB-ontwerp (Z) & \checkmark \\
      7 & Afwerking $2^{de}$ algoritme \& Fabricage Antenne (T) & \checkmark \\
       & Vergelijking Algoritmes & \checkmark\\
      8 & Uitmeten Antenne  & \ldots \\
      & Implementatie Microcontroller & \ding{55} \\
      \hline
    \end{tabular}
  \end{frame}
  \begin{frame}
    \frametitle{Planning}
    \begin{verse}
       "Failure is always an option"
    \end{verse}
    \pause
    \begin{itemize}
      \item Redesign Antenne
    \end{itemize}
  \end{frame}
  \begin{frame}
    \frametitle{TODO}
    \begin{itemize}
      \item Solderen PCB
      \item Testen PCB
      \item Implementatie van algoritmes op microcontroller
      \item Integratie
    \end{itemize}
  \end{frame}
\section{PCB Design}
\subsection{Onderdelen}
  \begin{frame}
    \frametitle{Onderdelen}
    \begin{itemize}
      \item Microcontroller: STM32F4
      \item Accelerometer
    \end{itemize}
  \end{frame}
  \begin{frame}
    \begin{figure}
      \begin{center}
        
      \end{center}
    \end{figure}
  \end{frame}
\section{Algoritmes}
\subsection{Ankers}
  \begin{frame}
    \frametitle{Opstelling}
    \begin{figure}
      \begin{center}
        
      \end{center}
    \end{figure}
  \end{frame}
  \begin{frame}
    \frametitle{Ankers}
    \begin{itemize}
      \item Gekende positie
      \item Afstand via pulsen $\Rightarrow$ UWB
      \item Meetruis
    \end{itemize}
    \begin{figure}
      \begin{center}
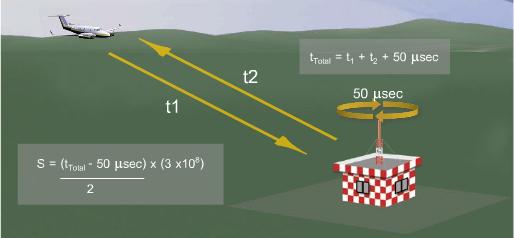
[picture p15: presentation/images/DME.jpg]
        
      \end{center}
    \end{figure}
  \end{frame}
\subsection{Lokalisatie Algoritme}
  \begin{frame}
    \frametitle{Algoritmes}
    \begin{itemize}
      \item LMS: Least Mean Square
      \item Kalman 
    \end{itemize}
  \end{frame}
  \begin{frame}
    \frametitle{Least Mean Square}
    \begin{itemize}
      \item Geen geheugen
        \begin{itemize}
          \item Geen invloed van het verleden
        \end{itemize}
      \item Wat indien er meer vergelijkingen dan onbekenden zijn?
        \begin{itemize}
          \item \# ankers $>$ \# dimensies + 1
        \end{itemize}
    \end{itemize}
    \begin{figure}
      \centering
        
    \end{figure}
  \end{frame}
  \begin{frame}
    \frametitle{Kalman Filter}
    \begin{itemize}
      \item Geheugen $\Rightarrow$ matrices
      \item Bewegingsvrijheid van de drone is beperkt
      \item 2 onderdelen:
        \begin{itemize}
          \item Voorspellen
          \item Meten en updaten
        \end{itemize}
    \end{itemize}
  \end{frame}
  \begin{frame}
    \frametitle{Uitbreiden Kalman Filter}
    \begin{itemize}
      \item Extra Sensoren (Sensor Fusion)
        \begin{itemize}
          \item Accelerometer
          \item Gyroscoop
          \item Hoogtemeter
          \item \ldots
        \end{itemize}
      \item Doel: nauwkeuriger volgen
    \end{itemize}
  \end{frame}
\subsection{Resultaten}
  \begin{frame}
    \frametitle{Resultaten: Simulaties}
    \begin{columns}[c]
      \begin{column}{.5\textwidth}
        \begin{figure}
          \begin{center}
            
          \end{center}
        \end{figure}
      \end{column}
      \begin{column}{.5\textwidth}
        \begin{figure}
          \begin{center}
            
          \end{center}
        \end{figure}
      \end{column}
    \end{columns}
  \end{frame}
  \begin{frame}
    \frametitle{Resultaten: Simulaties}
    \begin{figure}
      \begin{center}
        
      \end{center}
    \end{figure}
  \end{frame}
  \begin{frame}
    \frametitle{LMS vs. Kalman Filter}
    \begin{center}
    \begin{tabular}{|l|l|}
      \hline
      LMS & Kalman Filter \\
      \hline
      (+) Eenvoudiger & (-) Complexer \\
      (-) Ruwere schatting & (+) Nauwkeuriger \\
      \hline
    \end{tabular}
    \end{center}
  \end{frame}
  \addtocontents{toc}{\newpage}
  \section{UWB Antenne}
\subsection{Referentie}
  \begin{frame}
  \frametitle{Referentie}
  \begin{columns}[c]
  \begin{column}{0.5\textwidth}
    \begin{itemize}
      \item BroadSpec\texttrademark  UWB Antenne 
      \item Dipool: omni in azimuth
      \item Ontwerpsparameters:
      \begin{itemize}
        \item $\SI{3.1}{\giga\hertz}$ - $\SI{5.3}{\giga\hertz}$
        \item Gain nominaal $\approx \SI{3}{\decibel}$ 
        \item Lineaire fase respons
        \item Effici\"entie $\approx$ 90\%
      \end{itemize}
    \end{itemize}
    \end{column}

    \begin{column}{0.5\textwidth}
    \centering
      
    \end{column}
    \end{columns}

  \end{frame}

\subsection{Ontwerp}
  \begin{frame}
  \frametitle{Ontwerp UWB Antenne}
  \begin{columns}[c]
  \begin{column}{0.5\textwidth}
  \begin{itemize}
        \item UWB topologie
         \begin{itemize}
            \item Bow Tie
            \item Halter 
           \end{itemize}
        \item $S_{11}$ niet vlak, fase niet lineair
        \begin{itemize}
          \item ADS: optimaliseren
        \end{itemize}
        \item Black foam: $\epsilon_r = 1.495 \implies$ \\ Aromatisch poly: $\epsilon_r = 2.55$ 
      \end{itemize}
    \begin{figure}[H]
    
    \end{figure}
  \end{column}

  \begin{column}{0.5\textwidth}
    \centering
    \begin{figure}[H]
    
    \end{figure}
  \end{column}
  \end{columns}
  \end{frame}

  \begin{frame}
  \frametitle{Ontwerp UWB Antenne}
  \begin{itemize}
    \item Start: Rechthoekige Patch Antenne
      \begin{itemize}
        \item Lengte: Resonantie frequentie $f_0 = \SI{4.2}{\giga\hertz}$
              \begin{align}  L = \frac{c}{2 f_r \sqrt{\epsilon_r}}  \nonumber \end{align}
        \item Breedte: \begin{align} \text{Uitgestraald vermogen} \nonumber & \implies \text{Resonantie weerstand} \downarrow \\ & \implies \text{Bandbreedte} \uparrow, \text{Effici\"entie} \uparrow \nonumber \end{align}

      \end{itemize}
    \item Dimensies drone! $\implies$ Andere manier BW $\uparrow$ 
    \end{itemize}
  \end{frame}

  \begin{frame}
  \frametitle{Ontwerp UWB Antenne}
  
  \begin{columns}[c]
  \begin{column}{0.5\textwidth}
    \begin{itemize}
      \item Toevoegen \textit{Trap} $\implies$ BW $\uparrow$
      \item Partieel grondvlak
      \begin{itemize}
        \item Optimaliseren dimensies \begin{align} & \implies \text{Vlakke } S_{11} \nonumber \\ & \implies \text{Lineaire fase} \nonumber \end{align}
      \end{itemize}

    \end{itemize}
  \end{column}

  \begin{column}{0.5\textwidth}
  \centering
    
  \end{column}
  \end{columns}
  \end{frame}

\subsection{Simulatie}
  \begin{frame}
  \frametitle{ADS Simulatie}
    \begin{columns}[c]
      \begin{column}{0.5\textwidth}
      \begin{itemize}
        \item $S_{11} < \SI{-10}{\decibel}$: \\ $\SI{3.1}{\giga\hertz}$ - $\SI{6.7}{\giga\hertz}$
      \end{itemize}
        \begin{figure}
          
        \end{figure}

      \end{column}

      \begin{column}{0.5\textwidth}
      \begin{itemize}
        \item Lineaire fase respons: \\ OK
      \end{itemize}
        \begin{figure}
          
        \end{figure}
      \end{column}
    \end{columns}
  \end{frame}

  \begin{frame}
  \frametitle{ADS Simulatie}
    \begin{columns}[c]
      \begin{column}{0.5\textwidth}
      \begin{itemize}
        \item Effici\"entie 50\% - 96\% in gewenste band
      \end{itemize}
        \begin{figure}
          
        \end{figure}

      \end{column}

      \begin{column}{0.5\textwidth}
      \begin{itemize}
        \item Gain $\approx \SI{3}{\decibel}$ in gewenste band 
      \end{itemize}
        \begin{figure}
          
        \end{figure}
      \end{column}
    \end{columns}
  \end{frame}

\subsection{Prototype}
  \begin{frame}
  \frametitle{Prototype}
    \begin{itemize}
      \item Metingen worden verwerkt
    \end{itemize}
    \begin{columns}[c]
    \begin{column}{0.5\textwidth}
      
    \end{column}%
    \begin{column}{0.5\textwidth}
      
    \end{column}
    \end{columns}
  \end{frame}

\begin{frame}
  \begin{multicols}{2}
    \frametitle{Inhoudstafel}
    \tableofcontents[]
  \end{multicols}
\end{frame}
\end{document}

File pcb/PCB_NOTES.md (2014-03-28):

# Capacitors
- C7 ceramisch
- C1 en C2 ceramisch, hoge kwaliteit
- Decoupling (10n) ceramisch

# LEDS
- PWR: Constante verbinden wanneer bord is aangesloten op voeding
- ERR: Indicatie van error (PD12: zie LED4 in DISCOVERY)

# ESD
- Zeners: 1431155 (Langdurig: 5V op 3V3 lijn)
- TVS: 8737568 (Kort: ontlading)

# Reset button
- 2396053

# I2C adressen
- Accelerometer : 0011101b

# SWD programmer
1. VDD
2. SWCLK (PA14)
3. GND
4. SWDIO (PA13)
5. NRST  (NRST)
6. SWO   (PB3 )

R6 open laten

# RCM connectie
- Gebruik USART2

# Pin Headers
- [x] Communicatie antenne (6 + 2 x 6)
- [ ] Communicatie Drone (x)
- [x] Programmer (6)
- [x] I2C debugger (2)
- [ ] Power voor antenne-bord: (2 + 2 voor bord)
- [x] Jumper powerselectie (3)

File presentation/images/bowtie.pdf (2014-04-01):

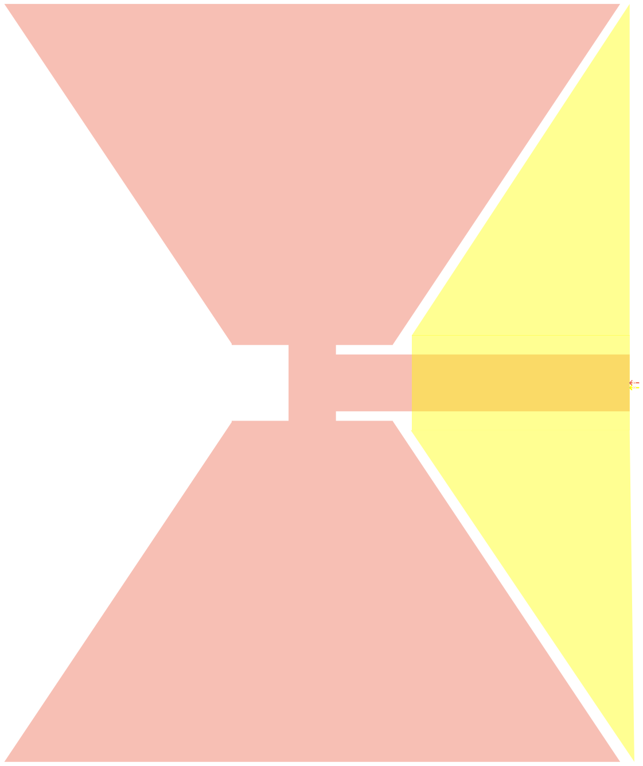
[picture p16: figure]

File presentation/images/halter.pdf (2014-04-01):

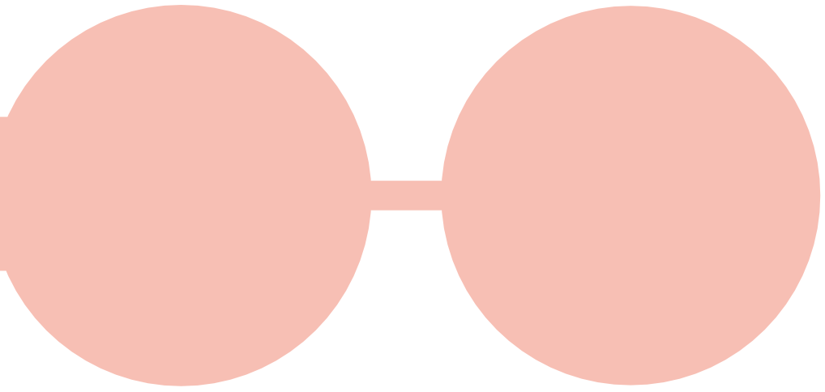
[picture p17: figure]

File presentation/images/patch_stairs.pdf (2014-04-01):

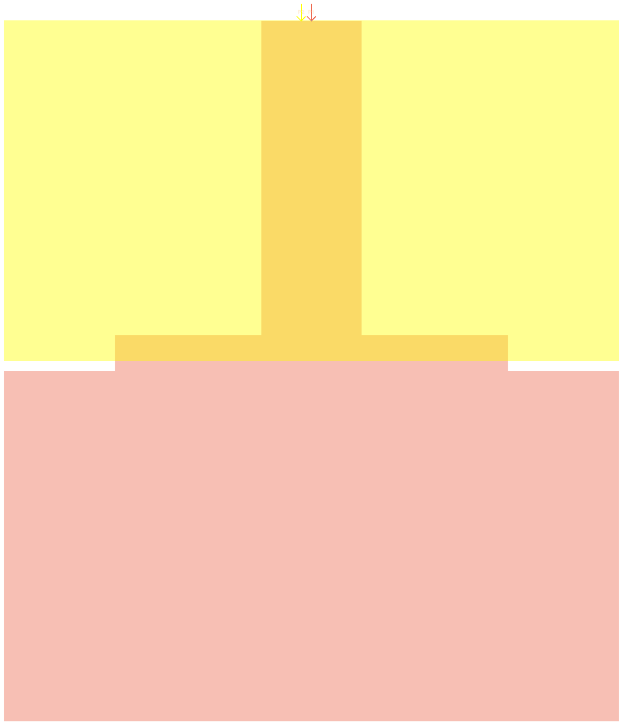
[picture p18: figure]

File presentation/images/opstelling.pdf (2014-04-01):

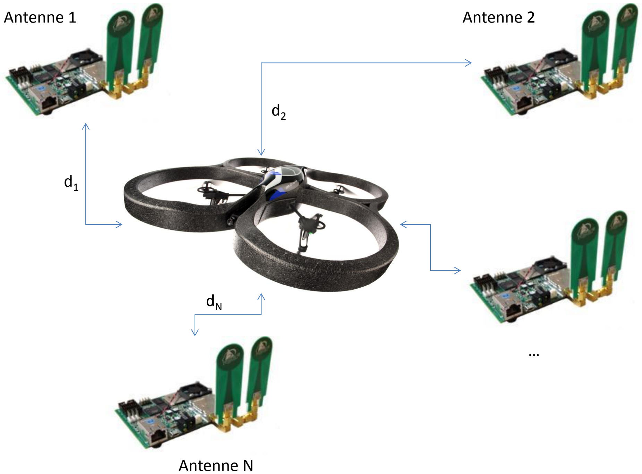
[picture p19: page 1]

Antenne 1 | Antenne 2

…

Antenne N

d1

d2

dN

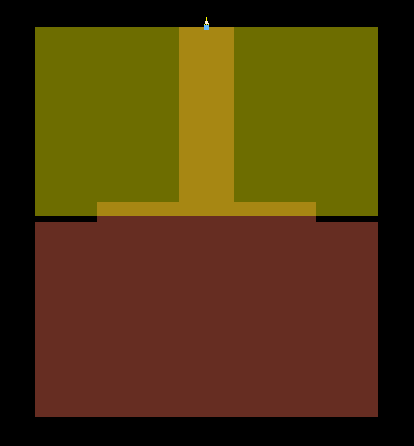
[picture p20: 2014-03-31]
report/images/antenne_ontwerp.png

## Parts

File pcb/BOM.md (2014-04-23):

# Bill of Materials

| Name | Qty  | Farnell | Remarks  |
| --- | :--: | ---: | ---  |
| STM32F407VGT6 | 1 | 2064368 | |
| CRYSTAL 8MHz  | 1 | 1842268 | |
| ACCELEROMETER | 1 | 1435588 | |
| VOLTAGE REG | 1 | 1578370 | |
| LED | 2 | 2099236 | red |
| LED | 2 | 2099239 | green |
| ZENER DIODE | 4 | 1431155 | MIN 10 |
| TVS DIODE | 7 | 8737568 | MIN 5 |
| CAP 20p | 2 | | CERAMIC  |
| CAP 1u | 9 | | |
| CAP 1u | 2 | | CERAMIC  |
| CAP 10u | 1 | | |
| CAP 100n | 2 | | CERAMIC  |
| CAP 10n | 9 | | CERAMIC  |
| CAP 2.2u | 2 | | |
| RES 0 ohm | 2 | | |
| RES 220 ohm | 1 | | |
| RES 10K ohm | 3 | | |
| RES 68 ohm | 2 | | |
| RES 56 ohm | 2 | | |
| RES 510 ohm | 1 | | |
| POWER JACK | 1 | | |
| PIN female | 20 | | |
| PIN male | 10 | | |

##To Add

- LEDs
- 56 ohm resistors

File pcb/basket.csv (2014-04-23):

Regelnummer | Farnell Ordercode | Hoeveelheid | Productomschrijving | Fabrikantnaam & -nummer | RoHS | Catalogusprijs | Beschikbaarheid | Regelprijs | Regelaantekening
1 | 1652909 | 6 | THICK FILM CHIP RESISTOR | VISHAY DRALORIC - CRCW080510K0FKTA | NO | 0.013 | Op voorraad | 0.08
2 | 2332762 | 10 | CAP, MLCC, C0G/NP0, 20PF, 50V, 0805 | AVX - 08055A200JAT2A | YES | 0.146 | Op voorraad | 1.46
3 | 2215224 | 2 | IC MCU, 32BIT, 1MB FLASH, 100LQFP | STMICROELECTRONICS - STM32F405VGT6 | YES | 11.46 | Op voorraad | 22.92
4 | 1653016 | 5 | RESISTOR, 0805, 510R, 1% | VISHAY DRALORIC - CRCW0805510RFKEA | Y-EX | 0.082 | Op voorraad | 0.41
5 | 2331777 | 10 | RESISTOR, POWER, 56R, 0.33W, 5%, 0805 | TE CONNECTIVITY - CRGH0805J56R | YES | 0.014 | Op voorraad | 0.14
6 | 1759246 | 20 | CAP, MLCC, X7R, 10NF, 50V, 0805 | MULTICOMP - MC0805B103K500CT | YES | 0.014 | Op voorraad | 0.28
7 | 2320857 | 30 | CAP, MLCC, X7R, 1UF, 10V, 0805 | MULTICOMP - MC0805B105K100CT | YES | 0.024 | Op voorraad | 0.72
8 | 1759166 | 10 | CAP, MLCC, X7R, 100NF, 25V, 0805 | MULTICOMP - MC0805B104K250CT | YES | 0.013 | Op voorraad | 0.13
9 | 1842268 | 2 | XTAL, 8.000MHZ, 18PF, HC-49S | TXC - 9B-8.000MAAJ-B | YES | 0.4 | Op voorraad | 0.8
10 | 2332063 | 10 | RESISTOR, POWER, 220R, 0.33W, 1%, 0805 | TE CONNECTIVITY - CRGH0805F220R | YES | 0.022 | Op voorraad | 0.22
11 | 8737568 | 15 | DIODE, TVS, 330W, SOD-523 | NXP - PESD3V3S1UB | YES | 0.11 | Op voorraad | 1.65
12 | 2309112 | 4 | RESISTOR, THICK FILM, 0R, 0.125W, 1% | MULTICOMP - MC0805S8F0000T5E | YES | 0.014 | Op voorraad | 0.06
13 | 2331778 | 10 | RESISTOR, POWER, 68R, 0.33W, 5%, 0805 | TE CONNECTIVITY - CRGH0805J68R | YES | 0.014 | Op voorraad | 0.14
14 | 2362105 | 10 | CAP, MLCC, X5R, 10UF, 6.3V, 0805 | MURATA - GRM21BR60J106KE01L | YES | 0.0605 | Op voorraad | 0.6
15 | 2099236 | 4 | LED, RED, 15MCD, 625NM, 0805 | KINGBRIGHT - KPT-2012EC | YES | 0.087 | Op voorraad | 0.35
16 | 1759416 | 10 | CAP, MLCC, X5R, 2.2UF, 10V, 0805 | MULTICOMP - MC0805X225K100CT | YES | 0.054 | Op voorraad | 0.54
17 | 2099239 | 4 | LED, 0805, GREEN, 12MCD, 568NM | KINGBRIGHT - KPT-2012SGC | YES | 0.087 | Op voorraad | 0.35
18 | 1578370 | 2 | IC, LDO, 3.3V, 150MA, SOT-23-5 | MICROCHIP - MCP1801T-3302I/OT | YES | 0.32 | Op voorraad | 0.64
19 | 1435588 | 2 | IC, ACCELEROMETER, 3 AXIS, 14LGA | STMICROELECTRONICS - LIS302DL | YES | 2.49 | Op voorraad | 4.98
 |  |  |  |  |  |  | Subtotaal: | 36.47
 |  |  |  |  |  |  | Promotiecode Korting: | 0.0
 |  |  |  |  |  |  | Totale kosten: | Onbekend
 |  |  |  |  |  |  | Subtotaal: | 36.47
 |  |  |  |  |  |  | BTW: | 7.66
 |  |  |  |  |  |  | Totaal: | 44.129999999999995

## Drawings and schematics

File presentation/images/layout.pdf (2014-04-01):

## BATDRN SDA

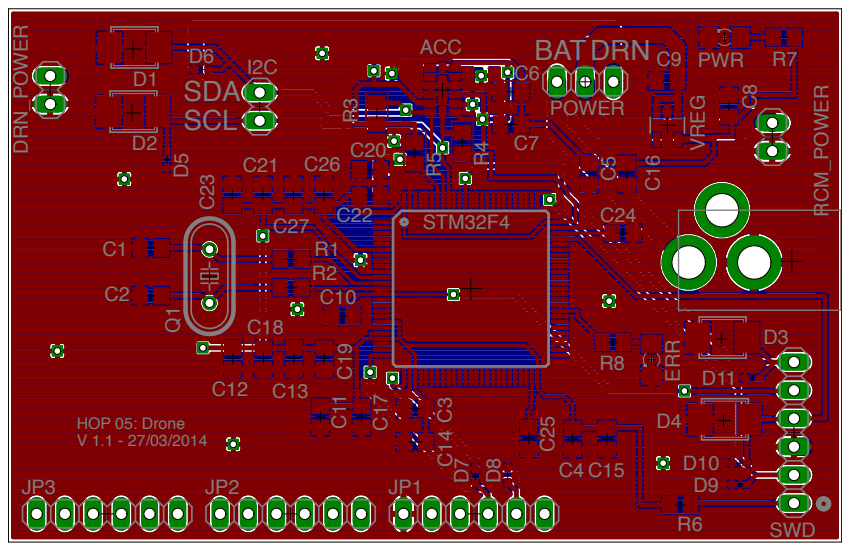
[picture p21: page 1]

C9 | PWR R7

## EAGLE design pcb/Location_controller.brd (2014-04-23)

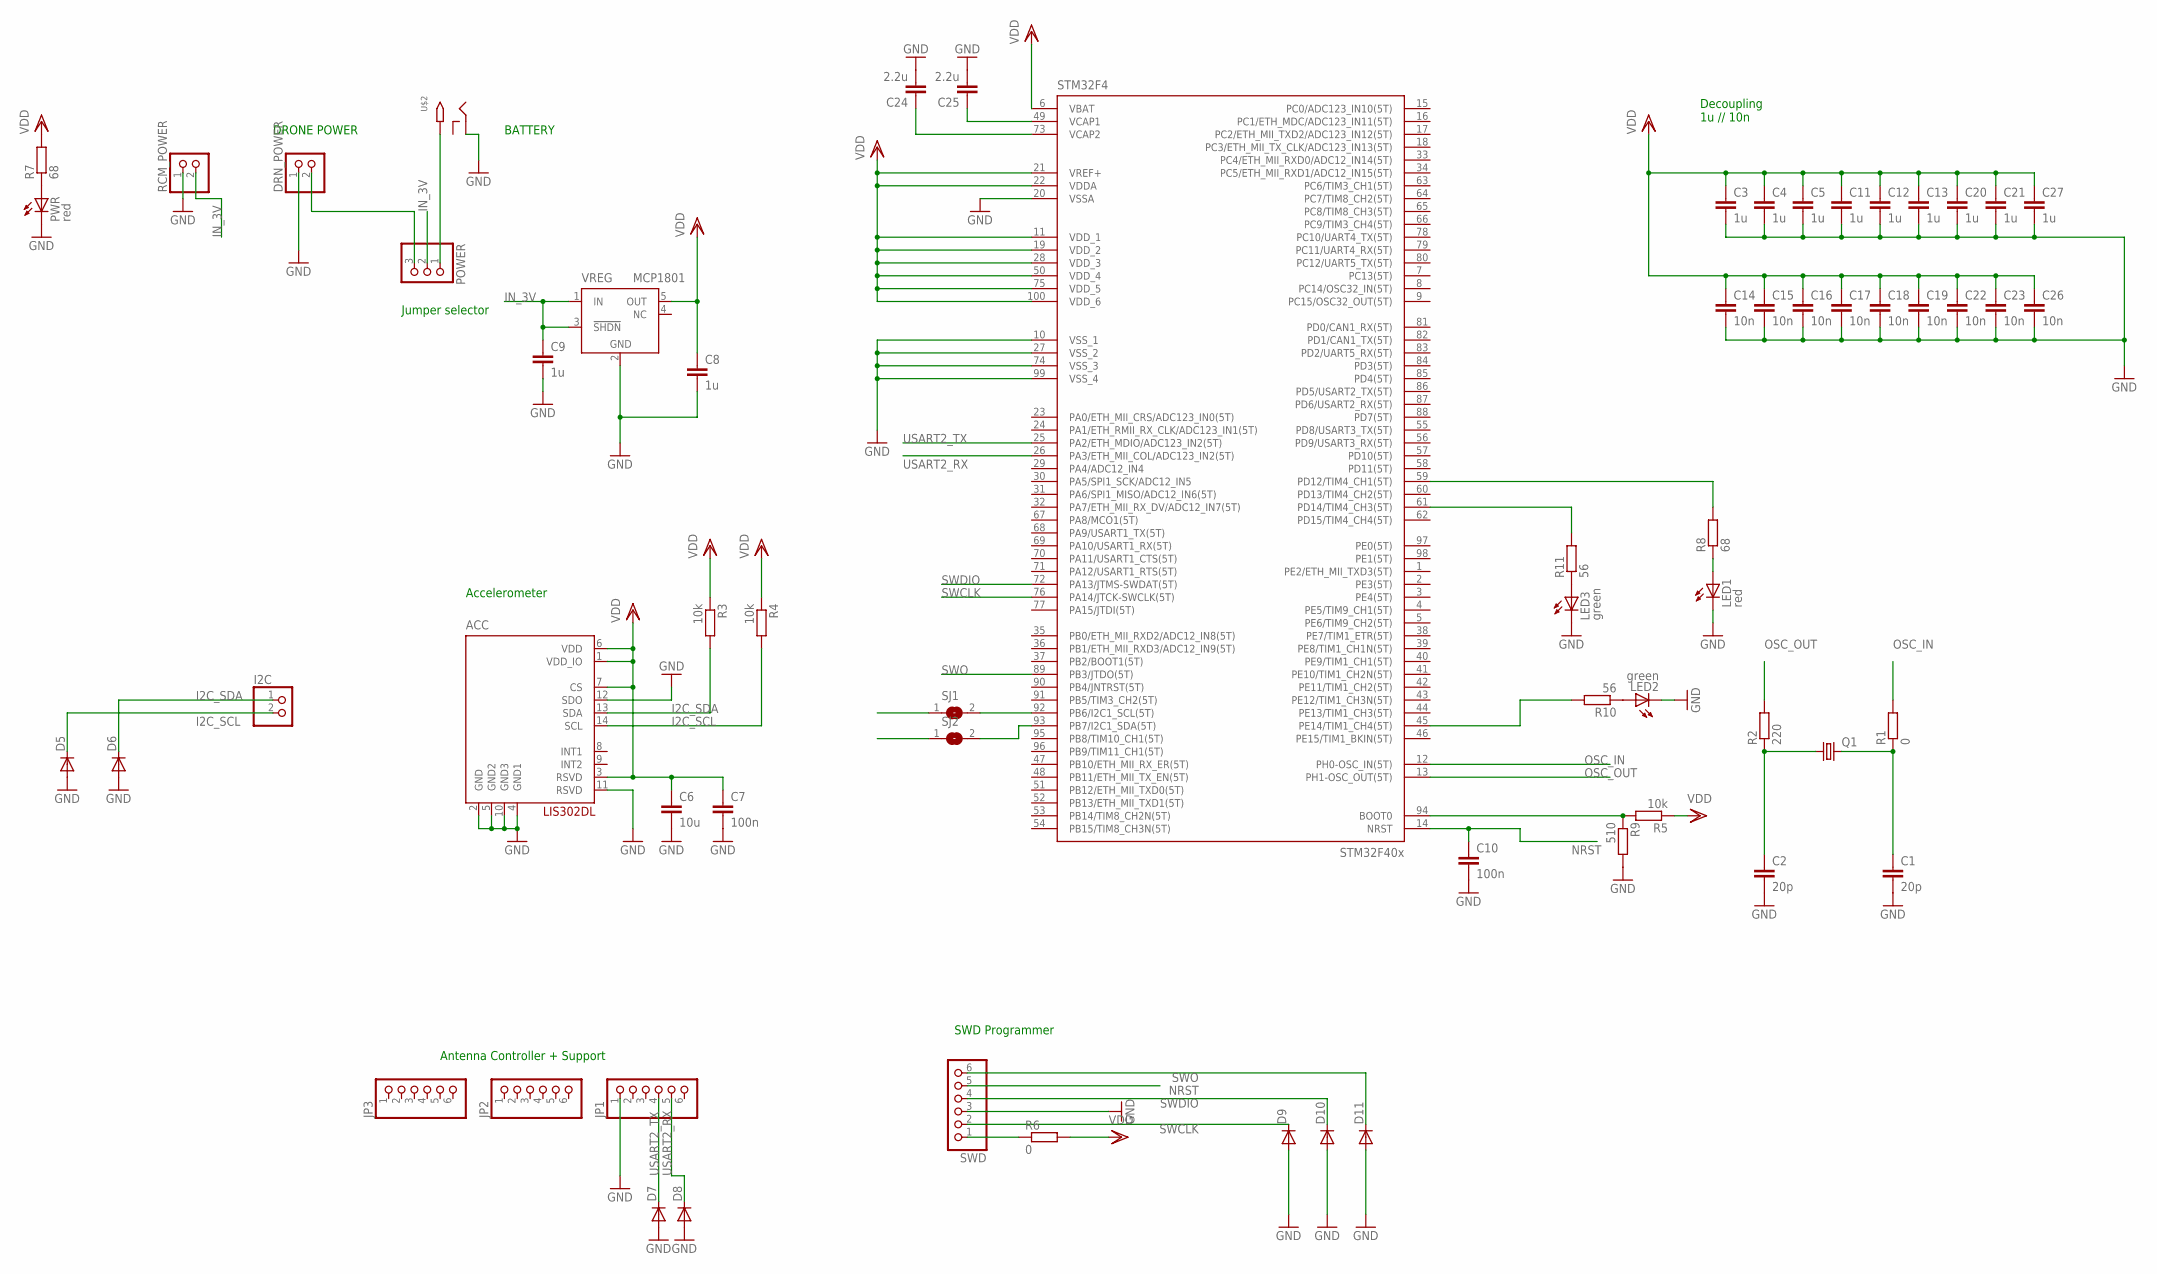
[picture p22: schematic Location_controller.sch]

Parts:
ACC: LIS302DL; LGA-14
C1, C2: 20p; C0805
C3, C4, C5, C8, C9, C11, C12, C13, C20, C21, C27: 1u; C0805
C6: 10u; C0805
C7, C10: 100n; C0805
C14, C15, C16, C17, C18, C19, C22, C23, C26: 10n; C0805
C24, C25: 2.2u; C0805
D5, D6, D7, D8, D9, D10, D11: DIODE-SOD523; SOD523
DRN_POWER: PINHD-1X2; 1X02
I2C: PINHD-1X2; 1X02
JP1, JP2, JP3: PINHD-1X6; 1X06
LED1: red; CHIPLED_0805
LED2, LED3: green; CHIPLED_0805
POWER: PINHD-1X3; 1X03
PWR: red; CHIPLED_0805
Q1: CRYSTALHC49S; HC49/S
R1, R6: 0; R0805
R2: 220; R0805
R3, R4, R5: 10k; R0805
R7, R8: 68; R0805
R9: 510; R0805
R10, R11: 56; R0805
RCM_POWER: PINHD-1X2; 1X02
SJ1, SJ2: SJ
STM32F4: STM32F407V; TQFP100
SWD: PINHD-1X6; 1X06
U$2: 2.1MMJACKTHM; PJ-102A
VREG: MCP1801; SOT23-5

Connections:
GND: ACC.2 (GND), ACC.4 (GND1), ACC.5 (GND2), ACC.10 (GND3), ACC.11 (RSVD), ACC.12 (SDO), C1.2, C2.2, C3.2, C4.2, C5.2, C6.2, C7.2, C8.2, C9.2, C10.2, C11.2, C12.2, C13.2, C14.2, C15.2, C16.2, C17.2, C18.2, C19.2, C20.2, C21.2, C22.2, C23.2, C24.2, C25.2, C26.2, C27.2, D5.A, D6.A, D7.A, D8.A, D9.A, D10.A, D11.A, DRN_POWER.1, JP1.1, LED1.C, LED2.C, LED3.C, PWR.C, R9.2, RCM_POWER.1, STM32F4.10 (VSS_1), STM32F4.20 (VSSA), STM32F4.27 (VSS_2), STM32F4.74 (VSS_3), STM32F4.99 (VSS_4), SWD.3, U$2.RING, VREG.2 (GND)
I2C_SCL: ACC.14 (SCL), D5.C, I2C.2, R4.2, SJ1.1
I2C_SDA: ACC.13 (SDA), D6.C, I2C.1, R3.2, SJ2.1
IN_3V: C9.1, POWER.2, RCM_POWER.2, VREG.1 (IN), VREG.3 (!SHDN)
unnamed: C2.1, Q1.1, R2.1
unnamed: C1.1, Q1.2, R1.1
unnamed: R5.2, R9.1, STM32F4.94 (BOOT0)
unnamed: DRN_POWER.2, POWER.3
unnamed: POWER.1, U$2.TIP
unnamed: R6.1, SWD.1
unnamed: C25.1, STM32F4.49 (VCAP1)
unnamed: C24.1, STM32F4.73 (VCAP2)
unnamed: PWR.A, R7.1
unnamed: LED1.A, R8.1
unnamed: R8.2, STM32F4.59 (PD12/TIM4_CH1(5T))
unnamed: LED2.A, R10.1
unnamed: R10.2, STM32F4.45 (PE14/TIM1_CH4(5T))
unnamed: LED3.A, R11.1
unnamed: SJ2.2, STM32F4.93 (PB7/I2C1_SDA(5T))
unnamed: R11.2, STM32F4.61 (PD14/TIM4_CH3(5T))
unnamed: SJ1.2, STM32F4.92 (PB6/I2C1_SCL(5T))
NRST: C10.1, STM32F4.14 (NRST), SWD.5
OSC_IN: R1.2, STM32F4.12 (PH0-OSC_IN(5T))
OSC_OUT: R2.2, STM32F4.13 (PH1-OSC_OUT(5T))
SWCLK: D9.C, STM32F4.76 (PA14/JTCK-SWCLK(5T)), SWD.2
SWDIO: D10.C, STM32F4.72 (PA13/JTMS-SWDAT(5T)), SWD.4
SWO: D11.C, STM32F4.89 (PB3/JTDO(5T)), SWD.6
USART2_RX: D8.C, JP1.5, STM32F4.26 (PA3/ETH_MII_COL/ADC123_IN2(5T))
USART2_TX: D7.C, JP1.4, STM32F4.25 (PA2/ETH_MDIO/ADC123_IN2(5T))
VDD: ACC.1 (VDD_IO), ACC.3 (RSVD), ACC.6 (VDD), ACC.7 (CS), C3.1, C4.1, C5.1, C6.1, C7.1, C8.1, C11.1, C12.1, C13.1, C14.1, C15.1, C16.1, C17.1, C18.1, C19.1, C20.1, C21.1, C22.1, C23.1, C26.1, C27.1, R3.1, R4.1, R5.1, R6.2, R7.2, STM32F4.6 (VBAT), STM32F4.11 (VDD_1), STM32F4.19 (VDD_2), STM32F4.21 (VREF+), STM32F4.22 (VDDA), STM32F4.28 (VDD_3), STM32F4.50 (VDD_4), STM32F4.75 (VDD_5), STM32F4.100 (VDD_6), VREG.5 (OUT)

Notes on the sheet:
Decoupling 1u // 10n
Accelerometer
Jumper selector
Antenna Controller + Support
SWD Programmer
BATTERY
DRONE POWER

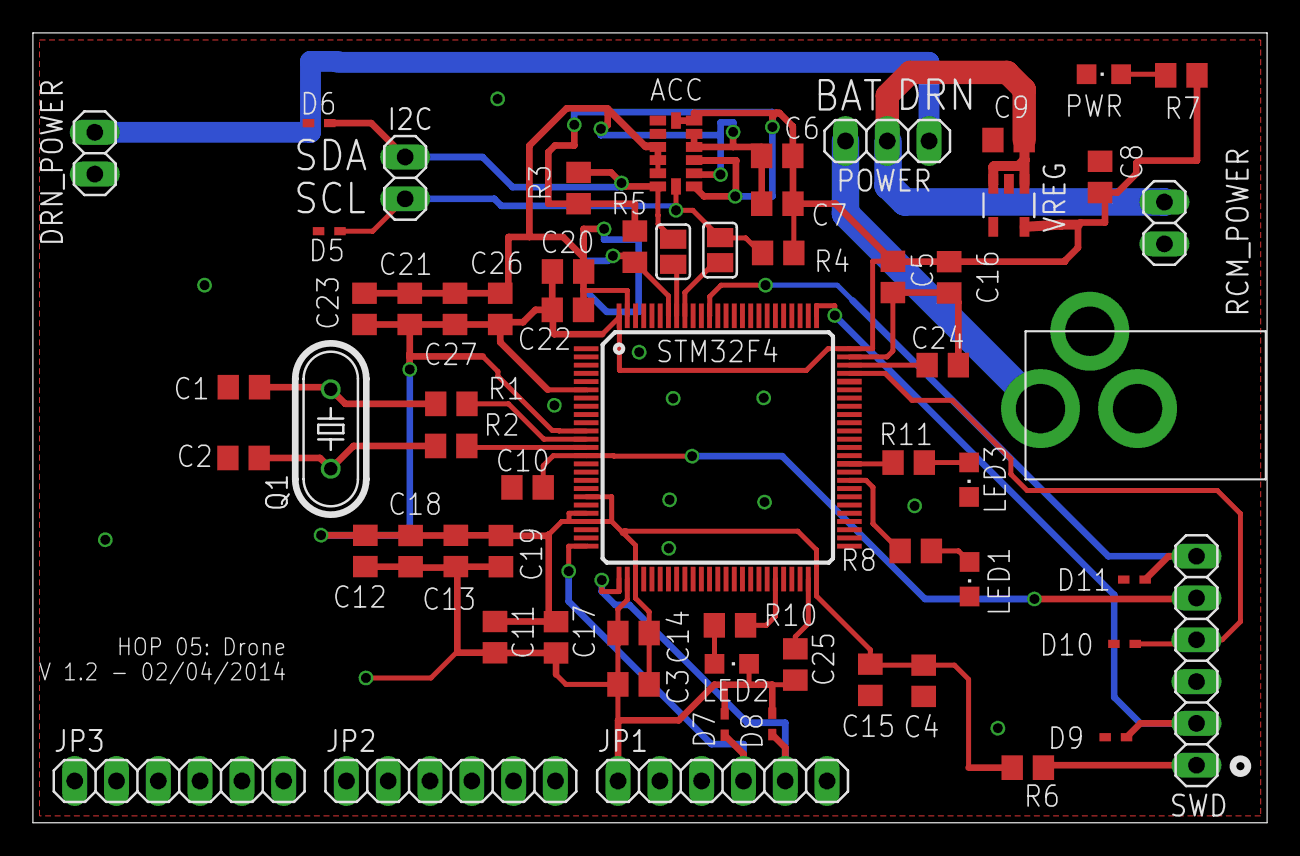
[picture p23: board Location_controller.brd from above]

Board: 2 copper layers, 75.0 x 48.0 mm, 64 parts (1 on the bottom side), 30 nets.

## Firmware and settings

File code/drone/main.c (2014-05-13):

/**
 *****************************************************************************
 **
 **  File        : main.c
 **
 **  Abstract    : main function.
 **
 **  Functions   : main, PerformRanging, int2float
 **
 **  Authors     : Thomas Deckmyn, Zeger Van de Vannet
 **
 *****************************************************************************
 */

#include "stm32f4xx_conf.h"
#include "stm32f4xx_it.h"
#include "arm_math.h"
#include "rcm.h"
#include "lcm.h"

#include "leds.h"
#include "main.h"
#include "lms.h"
#include "kalman.h"

#include "accelerometer.h"

#include "stm32f4xx_rng.h"

#include <stdlib.h>
#include <stdint.h>
#include <string.h>

//private functions:
void RNG_Config(void);
void PerformRanging(lcmMsg_LocInfo* locInfo, uint8_t nrAnchors, uint32_t* anchorID, uint8_t maxTrials);
float32_t int2float(uint32_t in);

//_____________________________________________________________________________
//
// static data
//_____________________________________________________________________________
static uint32_t RCM_id = 107;				// id of the node (given on the RCM device)
static bool bConnected = false;				// boolean if the node is connected to the central hub.

//_____________________________________________________________________________
//
// main - application entry point
//_____________________________________________________________________________

int main(void)
{
  // Initialization of Kalman Filter
  uint8_t i;
  float32_t weight_c_data[NR_SIGMAPOINTS];
  float32_t weight_m_data[NR_SIGMAPOINTS];
  float32_t position_data[DIMENSIONS], prev_position_data[DIMENSIONS], mkmin_data[DIMENSIONS];
  float32_t sigmapoints_data[NR_SIGMAPOINTS][DIMENSIONS];
  float32_t f_matrix_data[DIMENSIONS*DIMENSIONS];
  float32_t g_matrix_data[DIMENSIONS*(DIMENSIONS/2)];
  float32_t pk_data[DIMENSIONS*DIMENSIONS], pkmin_data[DIMENSIONS*DIMENSIONS];
  float32_t var_u_data[(DIMENSIONS/2)*(DIMENSIONS/2)];
  float32_t r_matrix_data[NR_ANCHORS*NR_ANCHORS];
  float32_t z_matrix_data[NR_ANCHORS * NR_SIGMAPOINTS];

  arm_matrix_instance_f32 weight_m, weight_c;
  position_t position, prev_position;
  position_t mkmin;
  position_t sigmapoints[NR_SIGMAPOINTS];
  arm_matrix_instance_f32 f_matrix, g_matrix;
  arm_matrix_instance_f32 pkmin, pk;
  arm_matrix_instance_f32 var_u, r_matrix;
  arm_matrix_instance_f32 z_matrix;

  // Data of the anchors: x, y, z coordinate plus measured distance from node
  float32_t anchors[NR_ANCHORS][4];

  // Initialize weight factors
  kalman_init_weight_factors(weight_m_data, weight_c_data);
  arm_mat_init_f32(&weight_m, NR_SIGMAPOINTS, 1, weight_m_data);
  arm_mat_init_f32(&weight_c, 1, NR_SIGMAPOINTS, weight_c_data);

  // Initialize position vectors
  kalman_init_position(position_data);
  kalman_init_position(prev_position_data);
  kalman_init_position(mkmin_data);
  arm_mat_init_f32(&position, DIMENSIONS, 1, position_data);
  arm_mat_init_f32(&prev_position, DIMENSIONS, 1, prev_position_data);
  arm_mat_init_f32(&mkmin, DIMENSIONS, 1, mkmin_data);

  // Initialize sigma points
  for (i = 0; i < NR_SIGMAPOINTS; i++) {
    kalman_init_sigmapoints(sigmapoints_data[i]);
    arm_mat_init_f32(&sigmapoints[i], DIMENSIONS, 1, sigmapoints_data[i]);
  }

  // Initialize F and G vectors
  kalman_init_f_matrix(f_matrix_data);
  kalman_init_g_matrix(g_matrix_data);
  arm_mat_init_f32(&f_matrix, DIMENSIONS, DIMENSIONS, f_matrix_data);
  arm_mat_init_f32(&g_matrix, DIMENSIONS, DIMENSIONS/2, g_matrix_data);

  // Initialize Pk and Pkmin
  kalman_init_dimensional_matrix(pk_data);
  kalman_init_dimensional_matrix(pkmin_data);
  arm_mat_init_f32(&pk, DIMENSIONS, DIMENSIONS, pk_data);
  arm_mat_init_f32(&pkmin, DIMENSIONS, DIMENSIONS, pkmin_data);

  // Initialize variance matrices
  kalman_init_variances(var_u_data, r_matrix_data);
  arm_mat_init_f32(&var_u, DIMENSIONS/2, DIMENSIONS/2, var_u_data);
  arm_mat_init_f32(&r_matrix, NR_ANCHORS, NR_ANCHORS, r_matrix_data);

  // Initialize Z matrix
  arm_mat_init_f32(&z_matrix, NR_ANCHORS, NR_SIGMAPOINTS, z_matrix_data);

  //configure delay in ms via systick:
  if (SysTick_Config(SystemCoreClock / 1000))
  {
    /* Capture error */
    while (1){
      LED_init(LED1);
      LED_on(LED1);
    }
  }

  // Initialize connection with the USART 2:
  // For the custom PCB
  while(initConn(USART2) != OK){
    //initialization failed:
    LED_init(LED2);
    LED_on(LED2);
    Delay(DELAY_TIME);
    LED_off(LED2);
  }

  // Initialize the on board accelerometer
  // Set the sensitivity to +/- 2.3g
  accelerometer_init();

  // Register this device with the main host
  char data2[1];
  data2[0] = LCM_MSG_REGISTER_NODE;			// message id for registration
  if(rcmDataSend(USED_ANTENNA, 1, &data2)){
    // success
  }


  // Localization loop
  while(true){

    rcmMsg_DataInfo recdata;
    bool err=rcmDataReceive(&recdata);

    uint8_t i=0;

    if(!err){
      lcmMsg_DoLoc* lcmMsg= (lcmMsg_DoLoc*)&(recdata.data);

      switch(lcmMsg->msgID){
        case LCM_MSG_DOLOCALIZATION:
          {

            uint32_t neighbourIDs[lcmMsg->nUsers + lcmMsg->nAnchors];

            while(i<lcmMsg->nUsers+lcmMsg->nAnchors){
              neighbourIDs[i] = lcmMsg->data[i];
              i++;
            }


            // check if this node can start ranging, if not, see if the node is in the user list
            if(lcmMsg->activeNodeID == RCM_id){

              bConnected = true;

              lcmMsg_LocInfo* locInfo = calloc(1, sizeof(lcmMsg_LocInfo));
              if(lcmMsg->options & LCMFLAG_COOP){
                // perform ranging with the anchors AND the other neighboring users
                PerformRanging(locInfo, (lcmMsg->nUsers+lcmMsg->nAnchors), neighbourIDs, 1);
                locInfo->nAnchors = lcmMsg->nUsers+lcmMsg->nAnchors;
              }else{
                // perform ranging with the anchors only.
                PerformRanging(locInfo, lcmMsg->nAnchors, neighbourIDs+lcmMsg->nUsers, 2);
                locInfo->nAnchors = lcmMsg->nAnchors;
              }


              // perform non-cooperative localization if required
              if(lcmMsg->options & LCMFLAG_ONBOARD_LOCALIZATION){
                int32_t acc_data[3];
                accelerometer_read(acc_data);
                locInfo->acc_x_axis = (float32_t) acc_data[0];
                locInfo->acc_y_axis = (float32_t) acc_data[1];
                locInfo->acc_z_axis = (float32_t) acc_data[2];

                if(!(lcmMsg->options & LCMFLAG_COOP)){
                  if(lcmMsg->options & LCMFLAG_KALMAN) {
                    uint8_t i = 0;
                    // perform Kalman Filtering

                    // Prediction Step
                    kalman_predict(&f_matrix, &g_matrix, &position, &pk, &var_u, &mkmin, &pkmin);
                    // Update new sigmapoints
                    kalman_update_sigmapoints(sigmapoints, mkmin, &pkmin);

                    // Measurement update
                    while(i < lcmMsg->nAnchors && i < NR_ANCHORS) {
                      anchors[i][0] = int2float(lcmMsg->data[i*3 + (lcmMsg->nUsers + lcmMsg->nAnchors)]) / 1000.0;
                      anchors[i][1] = int2float(lcmMsg->data[i*3 + 1 + (lcmMsg->nUsers + lcmMsg->nAnchors)]) / 1000.0;
                      anchors[i][2] = int2float(lcmMsg->data[i*3 + 2 + (lcmMsg->nUsers + lcmMsg->nAnchors)]) / 1000.0;
                      anchors[i][3] = (float32_t) locInfo->data[i].precisionRangeMm / 1000.0;
                      i++;
                    }

                    kalman_measurement_update(&z_matrix, anchors, sigmapoints, &weight_m, &weight_c, &r_matrix, &pkmin, &position, &pk);

                    // Report estimated location
                    locInfo->estim_x = position.pData[0];
                    locInfo->estim_y = position.pData[1];
                    locInfo->estim_z = position.pData[2];

                    // Report variance matrix
                    locInfo->variance[0] = pk.pData[0];
                    locInfo->variance[1] = pk.pData[1];
                    locInfo->variance[2] = pk.pData[7];

                  }else if(lcmMsg->options & LCMFLAG_3D){
                    // perform 3D localization
                    float32_t posEstimate[3] = {0.0f, 0.0f, 0.0f};
                    float32_t anchorsX[lcmMsg->nAnchors];
                    float32_t anchorsY[lcmMsg->nAnchors];
                    float32_t anchorsZ[lcmMsg->nAnchors];
                    uint32_t d[lcmMsg->nAnchors];

                    i=0;

                    // Fill in positions of anchor nodes in anchorsX,Y,Z and range measurement in d
                    while(i<lcmMsg->nAnchors){
                      anchorsX[i] = int2float(lcmMsg->data[i*3 + (lcmMsg->nUsers+lcmMsg->nAnchors)]);
                      anchorsY[i] = int2float(lcmMsg->data[i*3 + 1 + (lcmMsg->nUsers+lcmMsg->nAnchors)]);
                      anchorsZ[i] = int2float(lcmMsg->data[i*3 + 2 + (lcmMsg->nUsers+lcmMsg->nAnchors)]);
                      d[i] = (float)locInfo->data[i].precisionRangeMm;
                      i++;
                    }

                    // Calculate 3D positions and store in locInfo
                    arm_status errorStatus;
                    errorStatus = Calculate3DPosition(lcmMsg->nAnchors, posEstimate, anchorsX, anchorsY, anchorsZ, d);

                    locInfo->estim_x = posEstimate[0]/1000.0f;
                    locInfo->estim_y = posEstimate[1]/1000.0f;
                    locInfo->estim_z = posEstimate[2]/1000.0f;
                  }else {
                    // perform 2D localization
                    float32_t posEstimate[2] = {0.0f, 0.0f};
                    float32_t anchorsX[lcmMsg->nAnchors];
                    float32_t anchorsY[lcmMsg->nAnchors];
                    uint32_t d[lcmMsg->nAnchors];

                    i=0;
                    while(i<lcmMsg->nAnchors){
                      anchorsX[i] = int2float(lcmMsg->data[i*3 + (lcmMsg->nUsers+lcmMsg->nAnchors)]);
                      anchorsY[i] = int2float((float32_t)lcmMsg->data[i*3 + 1 + (lcmMsg->nUsers+lcmMsg->nAnchors)]);
                      d[i] = (float)locInfo->data[i].precisionRangeMm;
                      i++;
                    }

                    arm_status errorStatus;
                    errorStatus = Calculate2DPosition(lcmMsg->nAnchors, posEstimate, anchorsX, anchorsY, d);

                    locInfo->estim_x = posEstimate[0]/1000.0f;
                    locInfo->estim_y = posEstimate[1]/1000.0f;
                    locInfo->estim_z = 0;
                  }
                }else{
                  // perform cooperative localization.
                }
              }


              // send data to central hub
              locInfo->msgID = LCM_MSG_LOC_INFO;
              uint32_t msgSize = sizeof(lcmMsg_LocInfo) - sizeof(lcm_rangeInfo)*(LCM_MAX_NEIGHBOURS-locInfo->nAnchors);
              rcmDataSend(USED_ANTENNA, msgSize, locInfo);
              free(locInfo);

            }else{
              // check that the user is still connected with the central hub (i.e. in the user list)
              i = 0;
              bConnected = false;
              while(i<lcmMsg->nUsers){
                if(neighbourIDs[i] == RCM_id)
                  bConnected = true;
                i++;
              }
            }
          }
          break;
        case LCM_MSG_LOC_INFO:

          // This is not how it should be but ok..

          if(!bConnected){
            // Try to connect with the central hub
            char data[1];
            data[0] = LCM_MSG_REGISTER_NODE;		// message id for registration
            rcmDataSend(USED_ANTENNA, 1, &data);
          }
          // ignore
          break;

        case LCM_MSG_GET_CONNECTION:
          {
            if(!bConnected){
              // Try to connect with the central hub
              char data[1];
              data[0] = LCM_MSG_REGISTER_NODE;		// message id for registration
              rcmDataSend(USED_ANTENNA, 1, &data);
            }
          }
          break;

        default:
          // do nothing with unknown messages
          break;
      }
    }
  }

  // perform cleanup
  closeConn();
  return 0;
}


void PerformRanging(lcmMsg_LocInfo* locInfo, uint8_t nrAnchors, uint32_t* anchorID, uint8_t maxTrials)
{
  //first range with USED_ANTENNA then range with SECOND_ANTENNA for failed points

  rcmMsg_RangeInfo rangeInfo;
  rcmMsg_DataInfo dataInfo;
  uint8_t i=0;
  uint8_t trial=0;
  //first antenna
  while(i<nrAnchors){

    locInfo->data[i].anchorId = anchorID[i];
    trial++;

    // If no success after a number of trials, move to the next neighbour
    if(trial > maxTrials){
      locInfo->data[i].trials = trial;
      trial = 0;
      i++;
      continue;
    }

    // Determine range to a radio. May also get data and scan packets.
    rcmRangeTo(anchorID[i], USED_ANTENNA , 0, NULL, &rangeInfo, &dataInfo);

    if ((rangeInfo.msgType == RCM_RANGE_INFO) && (rangeInfo.rangeStatus == RCM_RANGE_STATUS_SUCCESS))
    {
      locInfo->data[i].precisionRangeMm = rangeInfo.precisionRangeMm;
      locInfo->data[i].precisionRangeErrEst = rangeInfo.precisionRangeErrEst;
      locInfo->data[i].channelRiseTime = rangeInfo.channelRiseTime;
      locInfo->data[i].reqLEDFlags = rangeInfo.reqLEDFlags;
      locInfo->data[i].respLEDFlags = rangeInfo.respLEDFlags;
      locInfo->data[i].timestamp = rangeInfo.timestamp;
      locInfo->data[i].coarseTOFInBins = rangeInfo.coarseTOFInBins;
      locInfo->data[i].trials = trial;

      // range with next neighbour
      trial = 0;
      i++;
    }

  }
}

// configure the random number generator, required for the particle filter.
void RNG_Config(void)
{
  // Enable RNG clock source, note that the RNG uses the AHB2: High speed Advanced Peripheral Bus (APB2)
  RCC_AHB2PeriphClockCmd(RCC_AHB2Periph_RNG, ENABLE);

  // RNG Peripheral enable
  RNG_Cmd(ENABLE);
}

float32_t int2float(uint32_t in){
  union{
    uint32_t 	here_write_float;
    float32_t   here_read_float;
  }convert;

  convert.here_write_float = in;

  return convert.here_read_float;
}

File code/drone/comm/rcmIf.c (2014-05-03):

//_____________________________________________________________________________
//
// #includes 
//_____________________________________________________________________________

#include <string.h>
#include <stdint.h>
#include <stdlib.h>
#include "rcmIf.h"

//
#define MAX_DATASIZE		1024
#define MAX_PACKETS 		5

//
//_____________________________________________________________________________
//
// static data
//_____________________________________________________________________________


// static data

// FIFO list with packets (Linked list)
typedef struct message{
	uint8_t *data;				// buffer to raw packet data (without header, packet size or CRC)
	uint16_t packet_size;		// size of the packet
	struct message *next;				// pointer to next packet
} message;

static message *head = NULL;			// Head of linked list
static message *last_message = NULL;	// last pointer in linked list
static uint8_t nPackets = 0;
static uint16_t crc=0;
static uint16_t sync = 0;				// field that gives the index of character received
static USART_TypeDef* USARTid = USART2;		// use USART2 by default


//_____________________________________________________________________________
//
// Private function prototypes 
//_____________________________________________________________________________

/* static void ResetMessage(void); */
static void writeUsart(unsigned volatile char*,uint8_t length);
static unsigned short crc16(void *buf, int len);


//_____________________________________________________________________________
//
// rcmIfInit - perform initialization
//_____________________________________________________________________________

void rcmIfInit(USART_TypeDef* usart_id)
{
	USARTid = usart_id;

	//interrupt priority RX defined in this file.
	/* USART configured as follow:
			- BaudRate = 115200 baud
			- Word Length = 8 Bits
			- One Stop Bit
			- No parity
			- Hardware flow control disabled (RTS and CTS signals)
			- Receive and transmit enabled
	*/

	/* initialise gpio pins */
	GPIO_InitTypeDef  GPIO_InitStructure;
	USART_InitTypeDef USART_InitStructure;
	NVIC_InitTypeDef  NVIC_InitStructure;

	USART_InitStructure.USART_BaudRate = 115200;
	USART_InitStructure.USART_WordLength = USART_WordLength_8b;
	USART_InitStructure.USART_StopBits = USART_StopBits_1;
	USART_InitStructure.USART_Parity = USART_Parity_No;
	USART_InitStructure.USART_HardwareFlowControl = USART_HardwareFlowControl_None;
	USART_InitStructure.USART_Mode = USART_Mode_Rx | USART_Mode_Tx;

	if(USARTid == USART2){
		// Enable USART 2
		// note: this uart uses pin PA2 and PA3 (TX and RX).

		/* Enable GPIO clock */
		RCC_AHB1PeriphClockCmd(RCC_AHB1Periph_GPIOA, ENABLE);

		/* Enable UART clock */
		RCC_APB1PeriphClockCmd(RCC_APB1Periph_USART2, ENABLE);

		GPIO_PinAFConfig(GPIOA, GPIO_PinSource2, GPIO_AF_USART2);
		GPIO_PinAFConfig(GPIOA, GPIO_PinSource3, GPIO_AF_USART2);

		//Configure USART2 pins:  Rx and Tx ----------------------------
		GPIO_InitStructure.GPIO_Pin =  GPIO_Pin_2 | GPIO_Pin_3;
		GPIO_InitStructure.GPIO_Speed = GPIO_Speed_50MHz;
		GPIO_InitStructure.GPIO_Mode = GPIO_Mode_AF;
		GPIO_InitStructure.GPIO_OType = GPIO_OType_PP;
		GPIO_InitStructure.GPIO_PuPd = GPIO_PuPd_UP;
		GPIO_Init(GPIOA, &GPIO_InitStructure);

		/* USART configuration */
		USART_Init(USART2, &USART_InitStructure);

		//enable the usart rx interrupt
		USART_ITConfig(USART2, USART_IT_RXNE, ENABLE);
		NVIC_InitStructure.NVIC_IRQChannel=USART2_IRQn;
		NVIC_InitStructure.NVIC_IRQChannelPreemptionPriority=0;
		NVIC_InitStructure.NVIC_IRQChannelSubPriority=0;
		NVIC_InitStructure.NVIC_IRQChannelCmd=ENABLE;
		NVIC_Init(&NVIC_InitStructure);

		/* Enable USART */
		USART_Cmd(USART2, ENABLE);
	}else if(USARTid == USART3){
		// Enable USART 3
		// note: this uart uses pin PD8 and PD9 (TX and RX).

		/* Enable GPIO clock */
		RCC_AHB1PeriphClockCmd(RCC_AHB1Periph_GPIOD, ENABLE);

		/* Enable UART clock */
		RCC_APB1PeriphClockCmd(RCC_APB1Periph_USART3, ENABLE);

		GPIO_PinAFConfig(GPIOD, GPIO_PinSource8, GPIO_AF_USART3);
		GPIO_PinAFConfig(GPIOD, GPIO_PinSource9, GPIO_AF_USART3);

		//Configure USART2 pins:  Rx and Tx ----------------------------
		GPIO_InitStructure.GPIO_Pin =  GPIO_Pin_8 | GPIO_Pin_9;
		GPIO_InitStructure.GPIO_Speed = GPIO_Speed_50MHz;
		GPIO_InitStructure.GPIO_Mode = GPIO_Mode_AF;
		GPIO_InitStructure.GPIO_OType = GPIO_OType_PP;
		GPIO_InitStructure.GPIO_PuPd = GPIO_PuPd_UP;
		GPIO_Init(GPIOD, &GPIO_InitStructure);

		/* USART configuration */
		USART_Init(USART3, &USART_InitStructure);

		//enable the usart rx interrupt
		USART_ITConfig(USART3, USART_IT_RXNE, ENABLE);
		NVIC_InitStructure.NVIC_IRQChannel=USART3_IRQn;
		NVIC_InitStructure.NVIC_IRQChannelPreemptionPriority=0;
		NVIC_InitStructure.NVIC_IRQChannelSubPriority=0;
		NVIC_InitStructure.NVIC_IRQChannelCmd=ENABLE;
		NVIC_Init(&NVIC_InitStructure);

		/* Enable USART */
		USART_Cmd(USART3, ENABLE);
	}

	/* Create first message in linked list */
	if(head == NULL){
	  head = (message*)malloc(sizeof(message));
	}

	sync = 0;
	head->next = NULL;
	head->data = NULL;
	head->packet_size = 0;
	last_message = head;
	nPackets = 0;
}

//_____________________________________________________________________________
//
// rcmIfClose - perform cleanup
//_____________________________________________________________________________

void rcmIfClose(void)
{
	if(USARTid == USART2){
		GPIO_DeInit(GPIOA);
		USART_DeInit(USART2);
	}else if(USARTid == USART3){
		GPIO_DeInit(GPIOD);
		USART_DeInit(USART3);
	}
}

//_____________________________________________________________________________
//
// rcmIfGetPacket - return RCM packet if not ready return 0;
//
//_____________________________________________________________________________

int rcmIfGetPacket(void *pkt_rec, uint16_t size_rec){
	// return the first packet in the FIFO list

	if(head->next != NULL){

		uint16_t pkt_size = head->packet_size;
		pkt_rec = memcpy(pkt_rec , head->data, pkt_size);

		message *tmp = head->next;
		free(head->data);
		free(head);
		head = tmp;
		nPackets--;

		return pkt_size;

	}else{
		// no packet ready
		return 0;
	}

}


//_____________________________________________________________________________
//
// rcmIfGMakePacket - void return
//

//_____________________________________________________________________________
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

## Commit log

2014-02-20 Initial setup of libraries with LED_blink demo
2014-02-22 Add PCB schematic/layout
    [Location_controller.brd, Location_controller.sch]
2014-02-22 Add crystal to layout
    [Location_controller.brd, Location_controller.sch]
2014-02-26 Add Accelerometer to PCB
    [Location_controller.brd, Location_controller.sch]
2014-02-26 Add Gyroscope to PCB
    [Location_controller.brd, Location_controller.sch]
2014-02-26 Add Voltage Regulator and application circuits
    [Location_controller.brd, Location_controller.sch]
2014-02-27 Add pin header
2014-02-27 UKF
    unscented kalman filter v1.0
2014-02-27 Move Unscented Kalman Filter to matlab script
    renames "matlab/Unscented Kalman Filter" to "matlab/Unscented_Kalman_Filter.m"
2014-03-05 Part one of Kalman Filter
2014-03-08 Add decoupling to schematic + initial layout
    [Location_controller.brd, Location_controller.sch]
2014-03-09 Add connections to RCM
    [Location_controller.brd, Location_controller.sch]
2014-03-09 Add SWD programmer connectors
    [Location_controller.brd, Location_controller.sch]
2014-03-11 Add more layering
    [Location_controller.brd]
2014-03-11 Further pcb layout routing
    [Location_controller.brd, Location_controller.sch]
2014-03-11 Add barrel DC-jack to pcb
    [Location_controller.brd, Location_controller.sch]
2014-03-12 Finish pcb routing
    [Location_controller.brd, Location_controller.sch]
2014-03-12 Silk-screening for pcb
    [Location_controller.brd]
2014-03-12 Add PWR and ERR indicator LEDs
    [Location_controller.brd, Location_controller.sch]
2014-03-14 Add I2C debug pins
    [Location_controller.brd, Location_controller.sch]
2014-03-15 Add LED error indicator function
    [leds.c, leds.h, main.c]
2014-03-16 Automatically attach USB device in Vagrant
2014-03-17 Add Zener Diodes to I2C pins
    [Location_controller.brd, Location_controller.sch]
2014-03-17 Add resistor to GND at BOOT0
    [Location_controller.brd, Location_controller.sch]
2014-03-17 Increase thickness on powerlines
    [Location_controller.brd]
2014-03-17 added zener to SWDIO EN SWO
    [Location_controller.brd, Location_controller.sch]
2014-03-17 Change silkscreening for Programmer
    [Location_controller.brd]
2014-03-17 Additional broadening of powerlines
    [Location_controller.brd]
2014-03-17 Add TVS for I2C and USART connections
    [Location_controller.brd, Location_controller.sch]
2014-03-19 Add ground plane
    [Location_controller.brd]
2014-03-19 Add ground plane on top
    [Location_controller.brd]
2014-03-19 Add antenna measurements
2014-03-19 Move crystal closer to microcontroller
    [Location_controller.brd]
2014-03-19 Add TVS to programmer pins
    [Location_controller.brd, Location_controller.sch]
2014-03-21 Swap power plug for correct dimensions
    [Location_controller.brd, Location_controller.sch]
2014-03-21 Move powerpins
    [Location_controller.brd]
2014-03-23 Move RCM_POWER pins to correct position
    [Location_controller.brd, Location_controller.sch]
2014-03-23 Add Bill of Materials
2014-03-23 Swap voltage regulator for one in stock
    [Location_controller.brd, Location_controller.sch]
2014-03-24 Connectors Farnell
2014-03-26 Fix Kalman filter
2014-03-27 Move powerpins to final location
    [Location_controller.brd]
2014-03-31 Presentation: Antenna reference and design path
2014-04-01 Presentation: Antenna finished
2014-04-02 Add additional LEDS to board
    See pcb/leds.md for pin mapping
    [Location_controller.brd, Location_controller.sch]
2014-04-03 Fix pcb remarks
    - Swap C4-C15 and C3-C14
    - Add vias under chip
    - Reroute trace under power jack
    [Location_controller.brd]
2014-04-03 Disconnect SDO pin on accelerometer
    [Location_controller.brd, Location_controller.sch]
2014-04-03 Add Farnell basket
    [basket.csv]
2014-04-04 Add solder bridges to disconnect accelerometer
    [Location_controller.brd, Location_controller.sch]
2014-04-04 Update basket
    [basket.csv]
2014-04-04 Add titles to antenna_comparison
2014-04-07 Add software LED drivers
2014-04-07 Rename flash_error() to generic LED_blink()
2014-04-14 Test functions with LEDs
2014-04-21 Report: Antenna Topology and Design
    Added paragraph on antenna topologies and design. TODO: Add optimized
    dimensions of patch in a table at end of paragraph. TODO: Paragraphs on
    simulation results and measurements anechoic chamber.
2014-04-24 Add source files to communicate with RCM over UART
2014-04-28 Report: Started section Antenna Simulation
2014-04-28 Missing semicolon in lms.h and bracket in lms.c
2014-04-28 Add small section about PCB
2014-04-28 Add accelerometer interface
2014-04-28 Add I2C read/write functions for accelerometer
2014-04-28 Initialize accelerometer control register
2014-04-29 Add accelerometer data to DoLoc struct
2014-05-03 Fix communication errors
    Add interrupt handlers to enable communication with RCM host
    [main.c, rcmIf.c]
2014-05-03 Improve section about PCB design
2014-05-03 Add read function to accelerometer
2014-05-04 Use uint8_t for accelerometer data
2014-05-04 Use auto increment to read accelerometer faster
2014-05-06 Fix initializations of matrices
    [main.c]
2014-05-06 Kalman filter : start section Kalman
2014-05-06 Send accelerometer data in rcm packets
2014-05-06 Fix typo in defines of the accelerometer
    [accelerometer.c]
2014-05-06 Fix conversion with accelerometer data
    [accelerometer.c]
2014-05-07 Solve LMS algoritme problems
    [main.c]
2014-05-07 Corrections to Antenna part of report
2014-05-08 report correct up to simulations antenna
2014-05-08 Fix some bad initialisations
    [main.c]
2014-05-08 Add Roll to Antenna measurement at 4.5GHz
2014-05-08 Add image of assembled PCB to report
2014-05-08 Added radpats to report, section antenna
2014-05-09 Discuss full ground plane in section PCB
2014-05-12 Finished antenna part presentation
2014-05-12 Fix errors in kalman
    [lcm.h, main.c]
2014-05-12 Change accelerometer sensitivity to 2.3g
2014-05-12 Fix error in data transfer with GUI
    [lcm.h, main.c]
2014-05-13 Add small schematic to explain ESD
